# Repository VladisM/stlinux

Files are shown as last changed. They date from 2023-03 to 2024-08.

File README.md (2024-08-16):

# STlinux

Simple board with STM32F446 and SDRAM that is capable of running MMU less linux
build. Purpose of this project is to learn new stuffs. It may seems like good
thing to have Linux in such small form factor but it isn't. MMU is somehow
important in security and using this approach to build device that will be
connected to the network is a bad idea.

This project using submodules. After clone use following to init them.

```bash
$ git submodule update --init --recursive
```

## System specification

* Hardware:
    * 32MB SDRAM
    * 8MB QSPI Flash
    * UART console, sd card slot, EEPROM
    * two LEDs and two buttons
* Software
    * Linux kernel 6.3
    * Busybox 1.36.1

## Manufacturing board

Gerber files required for manufacturing are stored in `board/ger` subdirectory.
To manufacture board you shall just find yourself a suitable manufacturer
and use latest archive.

To generate BOM you shall use KiCad and revisit folder `board/kicad`. All
project files are stored there.

After soldering board you should apply ftdi configuration into
integrated UART bridge. Correct configuration is provided
by the file `board/ftdi_configuration.xml`. For that you are going
to need Windows PC and FT_PROG tool (available on their website).

To test if board was correctly manufactured and most importantly
assembled. You can use firmware available in `board_test` folder.

Compile and load firmware, connect using serial port at speed of 115200
and follow instructions.

**Warning:** at this moment SDIO and SD Card slot test are
not implemented!

## Compile system and bootloader

Everything is compiled using clfs.sh script in root folder of this project. So,
if you want to compile whole system simply call following command. (note, adjust
number of cores for compilation using -j)

```bash
$ ./clfs.sh --build all -j 8
```

After some time, you can find all output images in `build/images/`. There are:

 * bootloader - u-boot.bin
 * linux kernel - zImage
 * device tree - stm32f446-stlinux.dtb
 * system image - clfs.uImage

Bootloader shall be loaded to the board using STLink, and shall be written
to the internal Flash memory of MCU.

```bash
st-flash write build/images/u-boot.bin 0x08000000
```

Other components are by default loaded from QSPI Flash, there are two ways how
to get them there.

 * Using SD card
 * Using serial port (legacy)

### Loading QSPI Flash using serial port

This method was used for first revision of board with nonworking SD card slot.
If you have second revision of board, use SD card, it is much more faster.

Once you are in u-boot console, you can use xmodem protocol to send all files
and then write them to the QSPI Flash. For writing there is mtd command. Follow
next code snippet.

```bash
> loadx
# send kernel file (zImage) using your console emulator
> mtd erase kernel
> mtd write kernel ${loadaddr}
> loadx
# send rootfs file (clfs.uImage) using your console emulator
> mtd erase rootfs
> mtd write rootfs ${loadaddr}
> loadx
# send dtb file (stm32f446-stlinux.dtb) using your console emulator
> mtd erase rootfs
> mtd write rootfs ${loadaddr}
```

Then you can simply reset the board or type `run bootcmd` and you should be
welcomed by kernel boot log.

### Loading QSPI Flash using SD card

Compared to using serial port, this one is much much faster because data are
transferred over SD card, not xmodem at 115200 bauds.

Create one partition on your SD card, format it as FAT32, and copy there
image files from build directory. Then insert your card to the board and run
following commands.

```bash
> fatload mmc 0:1 ${loadaddr} zImage
> mtd erase kernel
> mtd write kernel ${loadaddr}
> fatload mmc 0:1 ${loadaddr} clfs.uImage
> mtd erase rootfs
> mtd write rootfs ${loadaddr}
> fatload mmc 0:1 ${loadaddr} stm32f446-stlinux.dtb
> mtd erase dtb
> mtd write dtb ${loadaddr}
```

After reset, your board will boot from QSPI Flash or you can simply type
`run bootcmd`.

### Loading directly from SD card

If you are feeling lazy, just copypaste this to bootloader console. And it will boot.

```bash
fatload mmc 0:1 ${kernel_addr_l} zImage ; fatload mmc 0:1 ${rootfs_addr_l} clfs.uImage ; fatload mmc 0:1 ${dtb_addr_l} stm32f446-stlinux.dtb ; run set_args ; bootz ${kernel_addr_l} ${rootfs_addr_l} ${dtb_addr_l}
```

It will load everything from SD card into RAM and boot kernel that way.

## License

This project is using a lot of software components that are licensed under
various licenses. Always make sure to check what component are you working
with to prevent any misunderstanding.

Board manufacturing files, firmware for testing, and build script is licensed
using the Do What The Fuck You Want To Public License, Version 2,
as published by Sam Hocevar. See COPYING file for more details.

Note: CLFS is abbreviation from Cross Linux From Scratch, in general describing process
of cross compiling [Linux From Scratch](https://www.linuxfromscratch.org/). Please
also see [CLFS project](https://trac.clfs.org/). My work is influenced by these
projects and I learned from their materials a lot.

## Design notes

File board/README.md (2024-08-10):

# Board project files

In this directory all files required for manufacturing board are gathered.
Archives with gerber files are stored in `CAM` directory. Project for KiCad
can be found in `KiCad` directory. Configuration required for FTDI chip is
next to the gerber files in `CAM` directory. There is also a CubeMX project
located in `STM32CubeMX` folder.

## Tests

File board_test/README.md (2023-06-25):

# Board testing utility

Firmware for testing board. It can detect problems
on your assembled board. For more information please
visit [doc/readme/board_test.md](../doc/readme/board_test.md).

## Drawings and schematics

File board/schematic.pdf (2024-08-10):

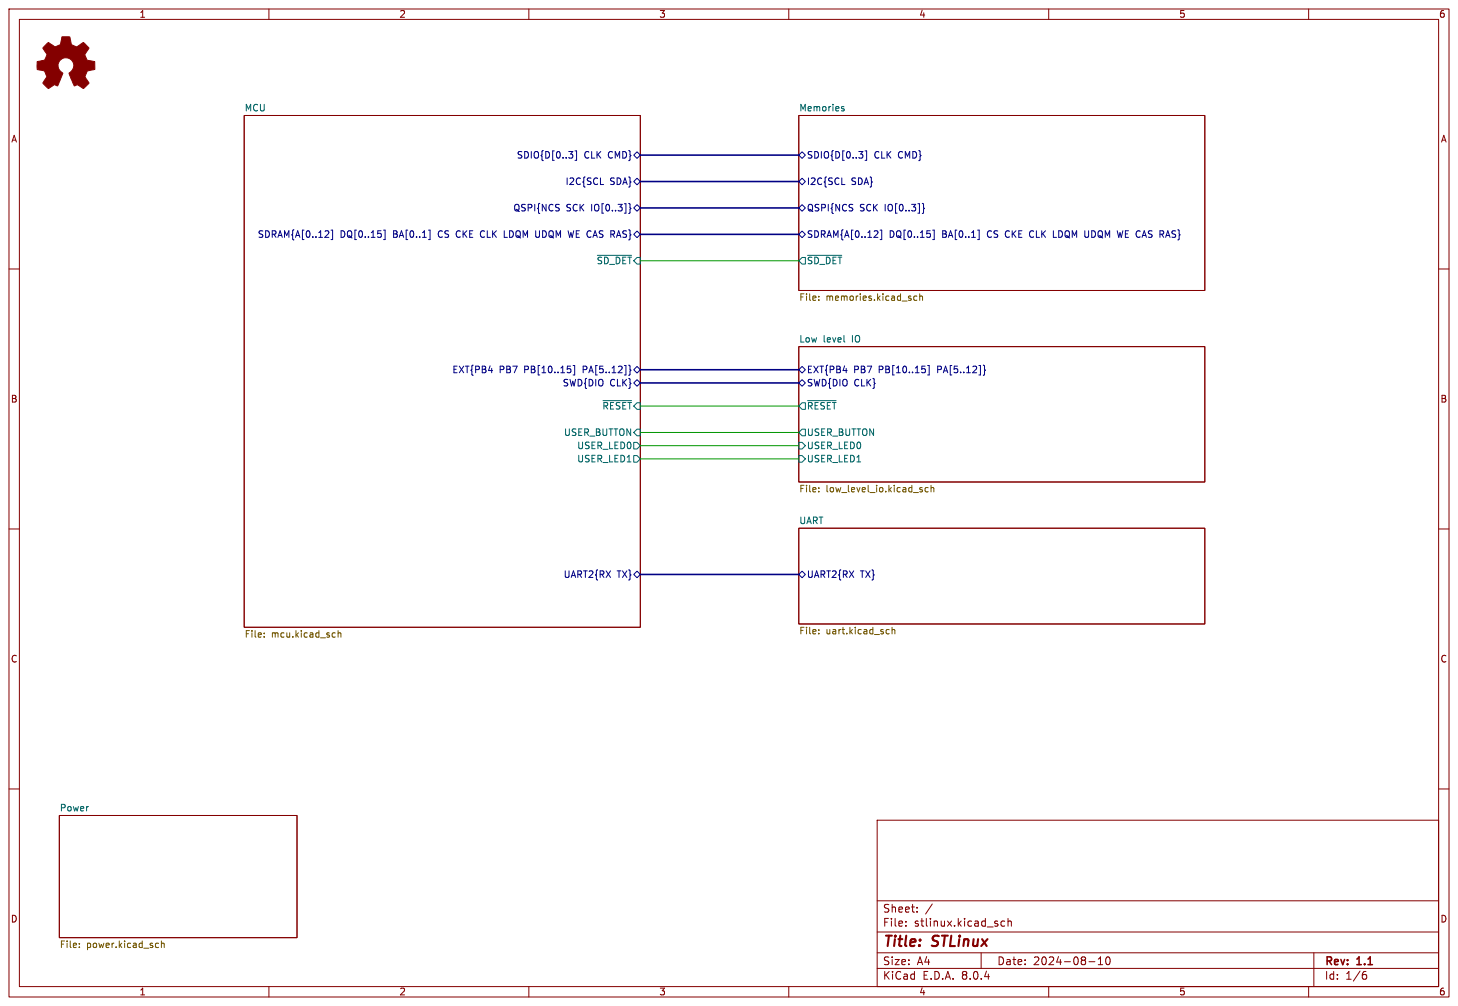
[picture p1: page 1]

File: stlinux.kicad_sch Sheet: / UART2{RX TX} UART

QSPI{NCS SCK IO[0..3]}

File: mcu.kicad_sch Power File: power.kicad_sch

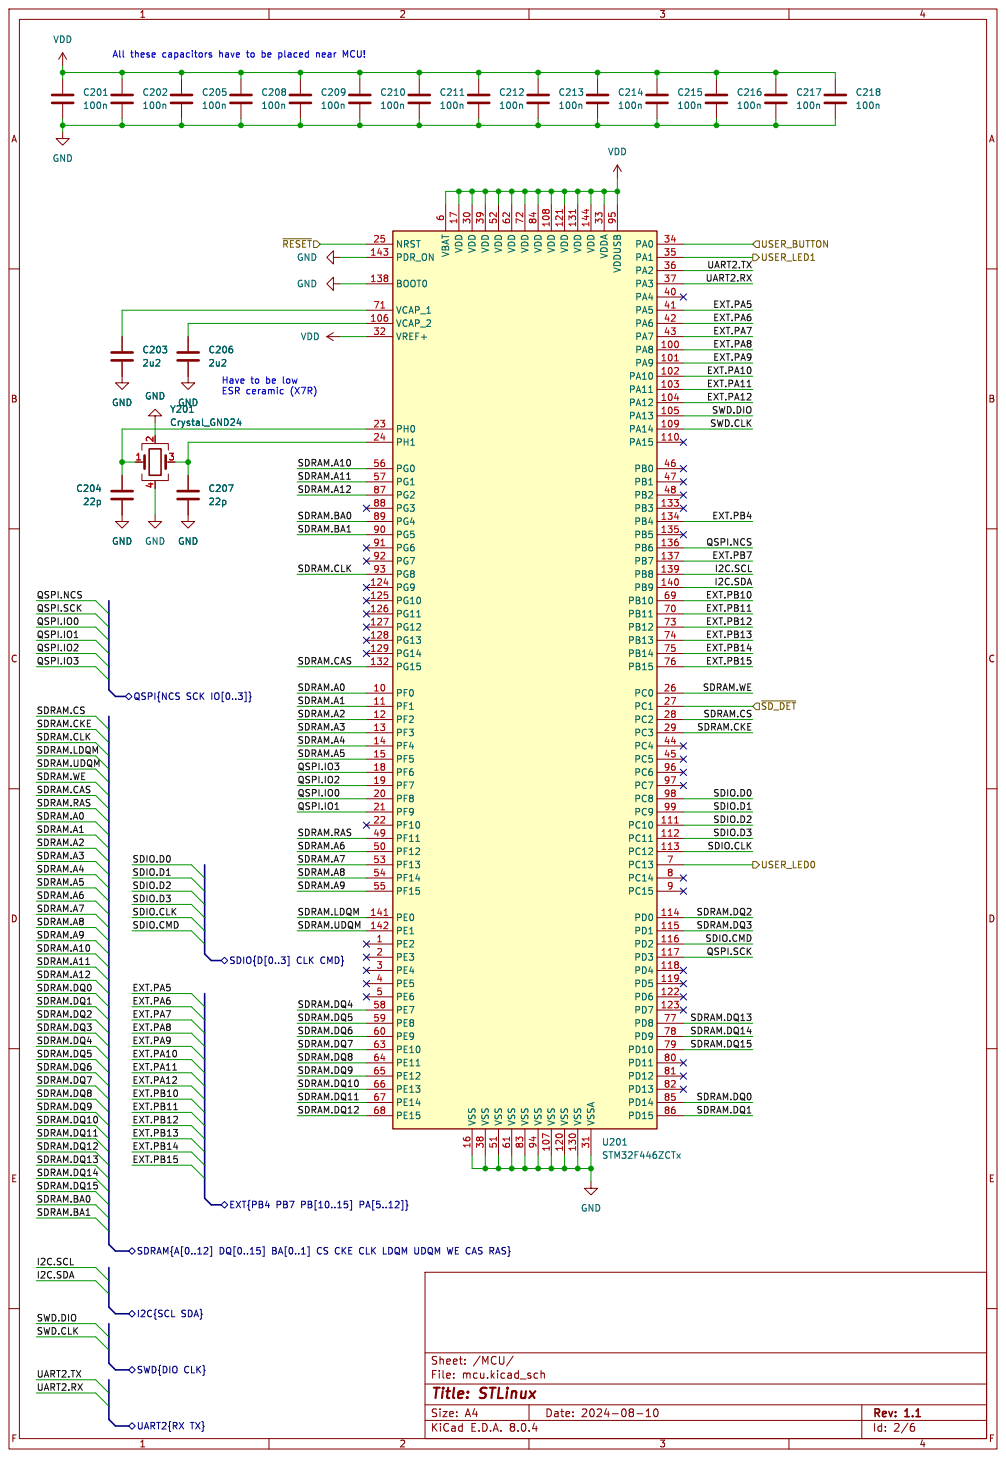
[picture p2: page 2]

EXT.PA8 EXT.PA9 EXT.PA6 EXT.PA11 EXT.PA10 EXT.PA5 UART2.TX UART2.RX QSPI.NCS

EXT.PB4 EXT.PB11 EXT.PB12 EXT.PB13 EXT.PB10

QSPI.SCK
SDRAM.CS QSPI.IO3 SDRAM.A0 SDRAM.RAS

EXT.PB15 EXT.PB14
SDRAM.CS QSPI.SCK
SDRAM.CKE

QSPI{NCS SCK IO[0..3]}

SDRAM.A2 SDRAM.A4 SDRAM.CLK
SDRAM.A3 SDRAM.CKE

SDRAM.LDQM
SDRAM.A1 SDRAM.UDQM
SDRAM.WE
SDRAM.CAS
EXT.PA6 EXT.PA5 SWD.CLK UART2.RX

SDIO.D3 SDRAM.DQ15 SDRAM.DQ13 SDRAM.DQ14 SDIO.D1 SDRAM.UDQM

File: mcu.kicad_sch Sheet: /MCU/
Id: 2/6 Title: STLinux

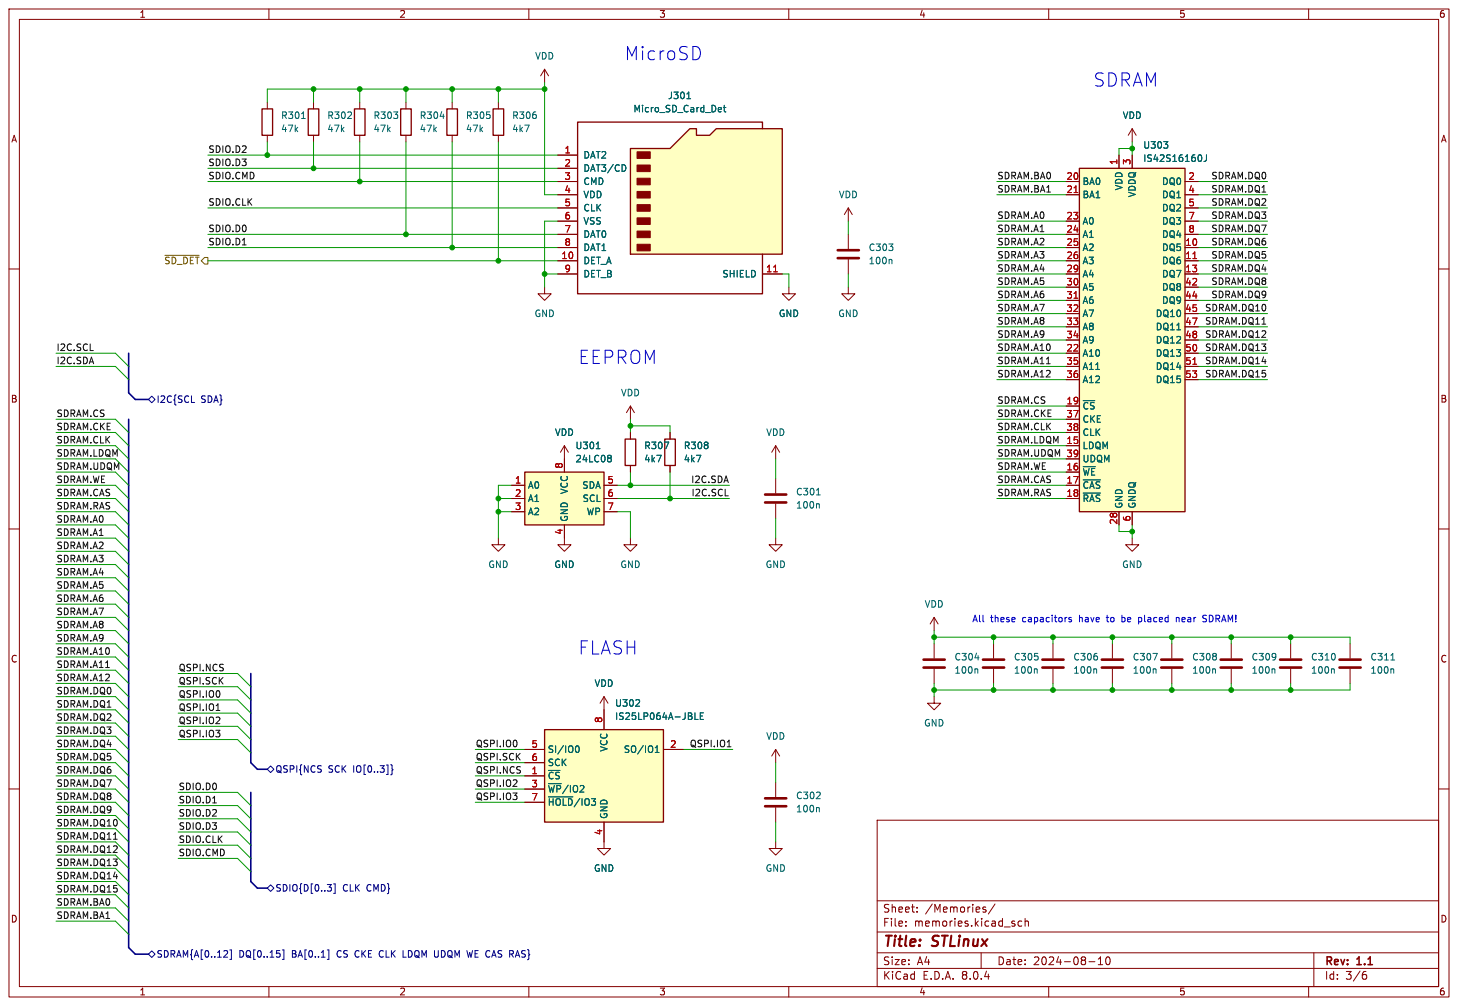
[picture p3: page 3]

J301 Micro_SD_Card_Det VDD
SDIO.D0 SDRAM.DQ12 SDRAM.DQ14 SDRAM.DQ13
SDIO.D1 QSPI.IO0 QSPI.NCS QSPI.SCK QSPI.IO3 SDIO.CMD
~{SD_DET}

SDRAM
SDRAM.A2 SDRAM.UDQM
SDRAM.A7 SDRAM.A8 SDRAM.A9 SDRAM.A10 SDRAM.A5 SDRAM.A11 SDRAM.A12 SDRAM.CS

3 A5 30 A6 31 A7 32 A8 33 A9 34 A11 35 A12 36 CKE 37 CLK 38 UDQM 39 DQ1 4 DQ8 42 DQ9 44 DQ10 45 DQ11 47 DQ12 48 DQ2 5 DQ13 50 DQ14 51 DQ15 53 GNDQ

SDRAM.DQ12 SDRAM.DQ14 SDRAM.DQ15 SDRAM.DQ4 SDRAM.DQ10 SDRAM.CKE

4 SDA 5 SCL 6 WP 7 VCC

4 SI/IO0 5 SCK 6 ~{HOLD}/IO3 7 VCC

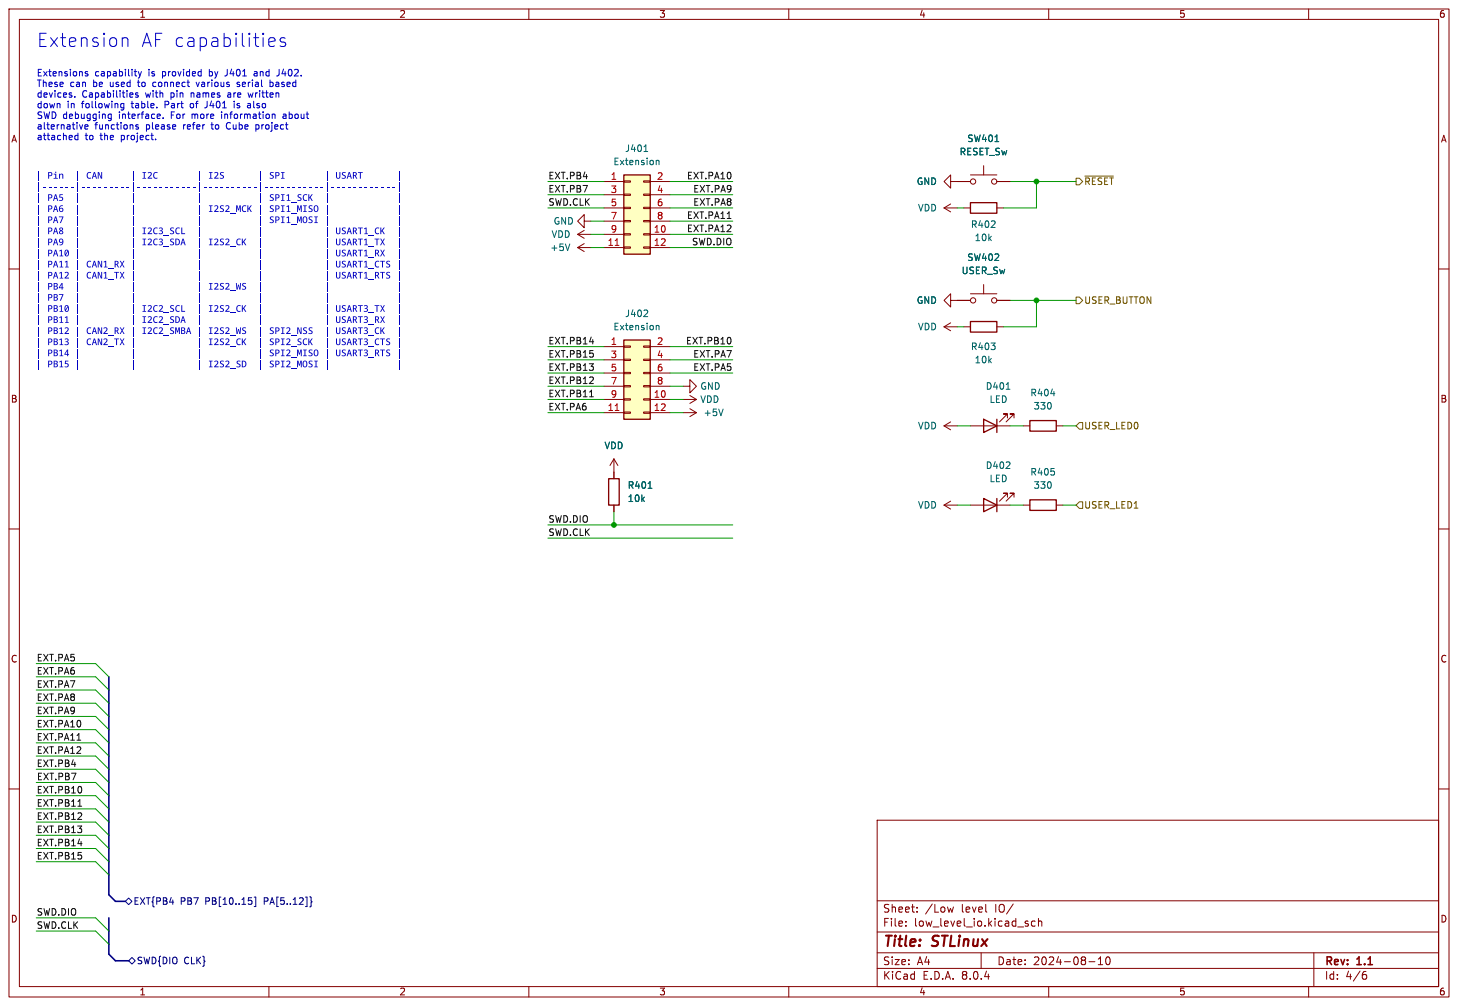
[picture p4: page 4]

EXT.PA11 EXT.PA6 SWD.DIO

EXT.PB11 EXT.PB15 EXT.PB12 EXT.PA11 EXT.PA9

EXT.PA5 SWD.CLK
EXT.PB12 EXT.PA8 EXT.PA6 EXT.PA7 EXT.PB11 EXT.PA12 EXT.PB4 EXT.PB7 EXT.PB10 EXT.PB15 EXT.PB13 EXT.PB14

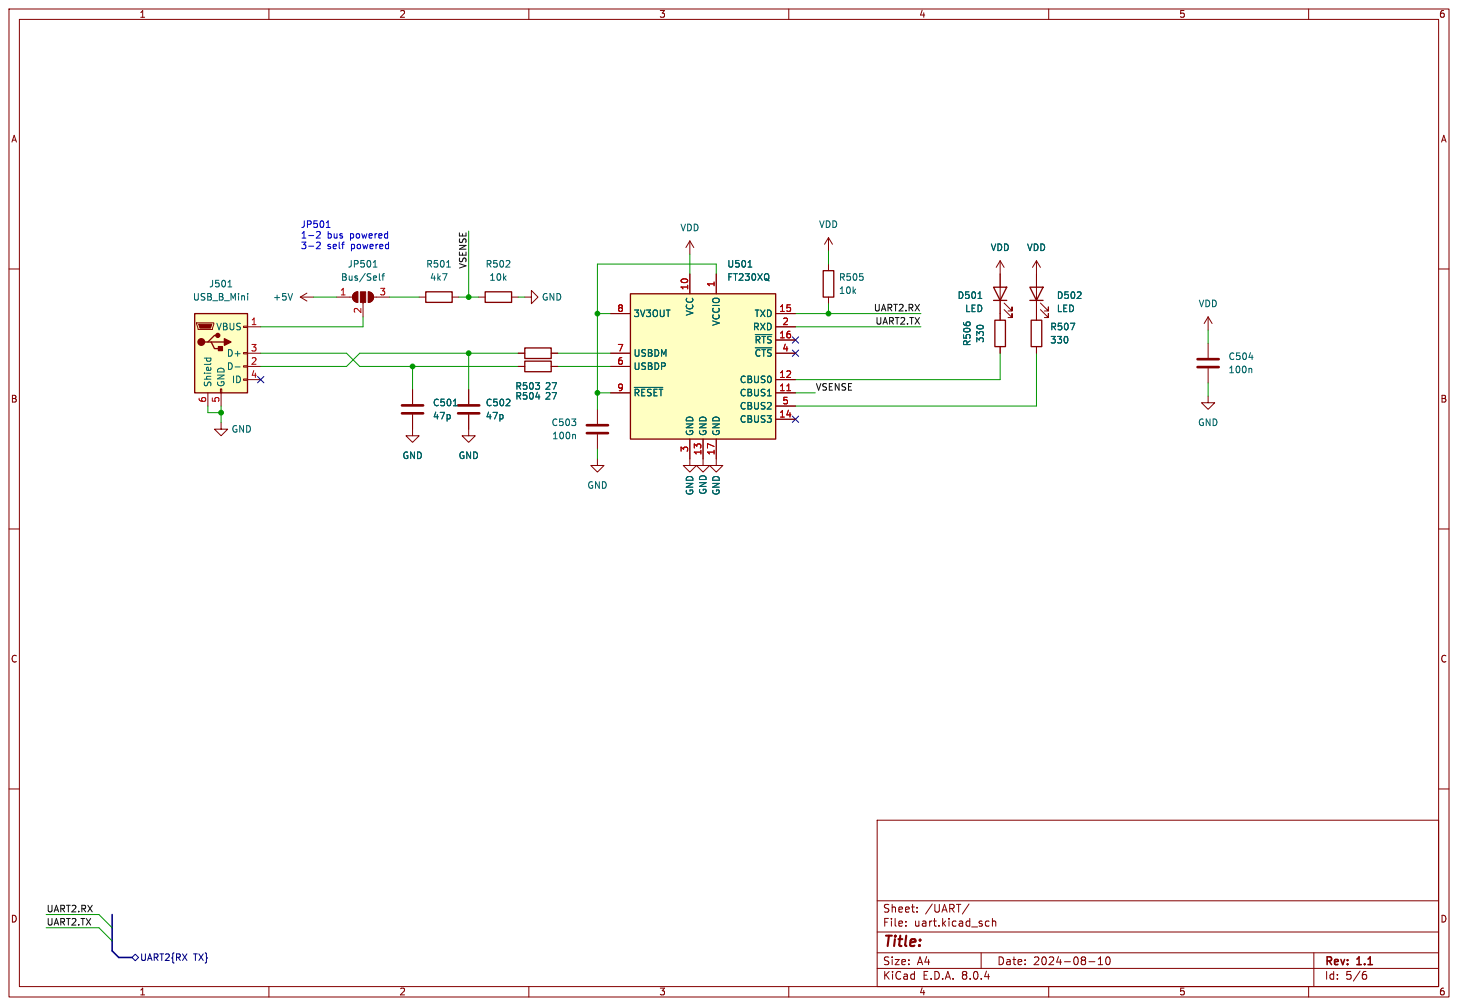
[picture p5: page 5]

1 VCC 10 CBUS1 11 CBUS0 12 GND 13 CBUS3 14 TXD 15 ~{RTS}16 GND 17 RXD 2 GND

Id: 5/6 Title: File: uart.kicad_sch Sheet: /UART/

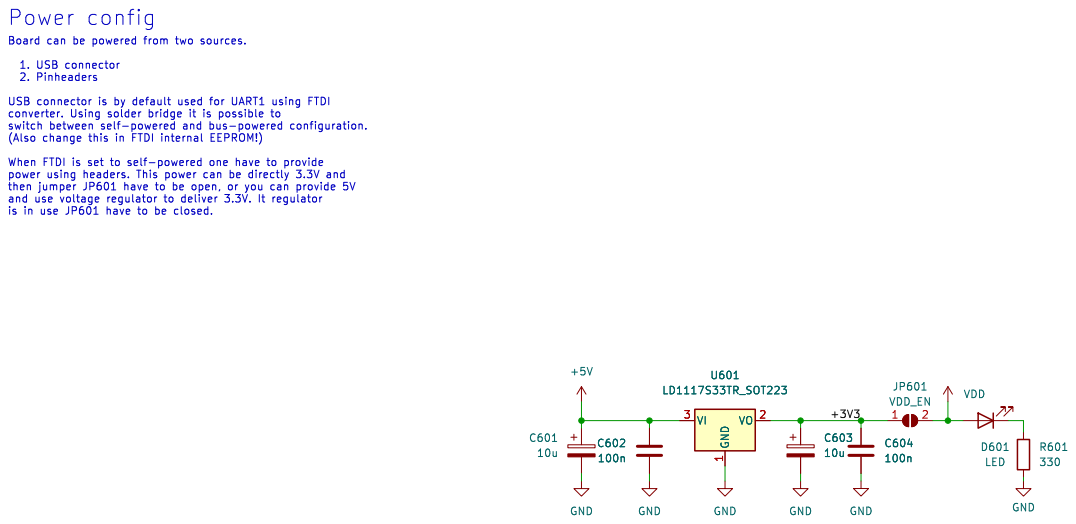
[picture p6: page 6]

then jumper JP601 have to be open, or you can provide 5V

Id: 6/6 Title: File: power.kicad_sch Sheet: /Power/

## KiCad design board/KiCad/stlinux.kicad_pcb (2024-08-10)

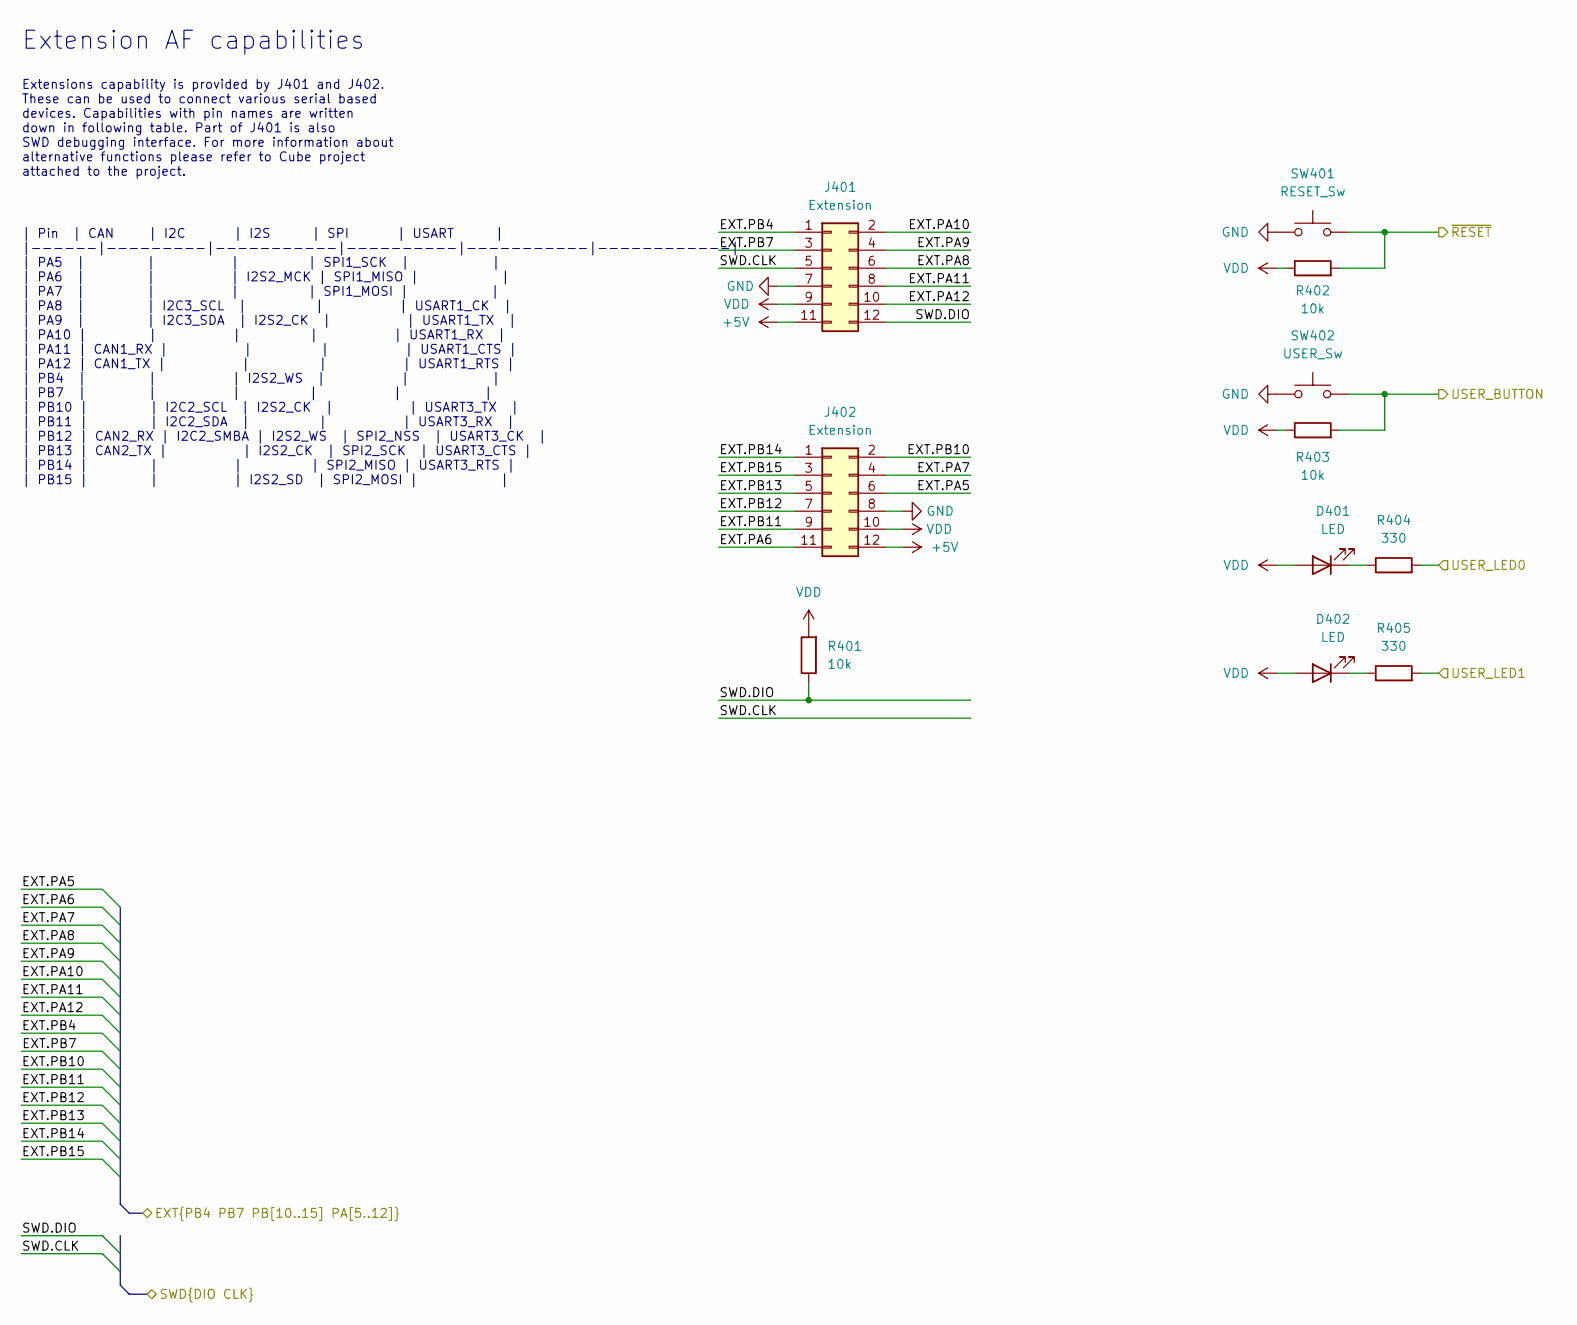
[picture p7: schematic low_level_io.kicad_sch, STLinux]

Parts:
D401, D402: LED; LED_1206_3216Metric_Pad1.42x1.75mm_HandSolder
J401, J402: Extension; PinSocket_2x06_P2.54mm_Vertical_SMD
R401, R402, R403: 10k; R_0603_1608Metric_Pad0.98x0.95mm_HandSolder
R404, R405: 330; R_0603_1608Metric_Pad0.98x0.95mm_HandSolder
SW401: RESET_Sw; SW_Push_1P1T_NO_6x6mm_H9.5mm
SW402: USER_Sw; SW_Push_1P1T_NO_6x6mm_H9.5mm

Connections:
+5V: J401.11, J402.12; also elsewhere on the board
/Low level IO/EXT.PA5: J402.6; also elsewhere on the board
/Low level IO/EXT.PA6: J402.11; also elsewhere on the board
/Low level IO/EXT.PA7: J402.4; also elsewhere on the board
/Low level IO/EXT.PA8: J401.6; also elsewhere on the board
/Low level IO/EXT.PA9: J401.4; also elsewhere on the board
/Low level IO/EXT.PA10: J401.2; also elsewhere on the board
/Low level IO/EXT.PA11: J401.8; also elsewhere on the board
/Low level IO/EXT.PA12: J401.10; also elsewhere on the board
/Low level IO/EXT.PB4: J401.1; also elsewhere on the board
/Low level IO/EXT.PB7: J401.3; also elsewhere on the board
/Low level IO/EXT.PB10: J402.2; also elsewhere on the board
/Low level IO/EXT.PB11: J402.9; also elsewhere on the board
/Low level IO/EXT.PB12: J402.7; also elsewhere on the board
/Low level IO/EXT.PB13: J402.5; also elsewhere on the board
/Low level IO/EXT.PB14: J402.1; also elsewhere on the board
/Low level IO/EXT.PB15: J402.3; also elsewhere on the board
/Low level IO/SWD.CLK: J401.5; also elsewhere on the board
/Low level IO/SWD.DIO: J401.12, R401.1; also elsewhere on the board
/Low level IO/USER_BUTTON: R403.2, SW402.2; also elsewhere on the board
/Low level IO/USER_LED0: R404.2; also elsewhere on the board
/Low level IO/USER_LED1: R405.2; also elsewhere on the board
/Low level IO/~RESET: R402.2, SW401.2; also elsewhere on the board
GND: J401.7, J402.8, SW401.1, SW402.1; also elsewhere on the board
unnamed: D401.1 (K), R404.1
unnamed: D402.1 (K), R405.1
VDD: D401.2 (A), D402.2 (A), J401.9, J402.10, R401.2, R402.1, R403.1; also elsewhere on the board

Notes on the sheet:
| Pin | CAN | I2C | I2S | SPI | USART | |------|---------|-----------|----------|-----------|------------| | PA5 | | | | SPI1_SCK | | | PA6 | | | I2S2_MCK | SPI1_MISO | | | PA7 | | | | SPI1_MOSI | | | PA8 | | I2C3_SCL | | | USART1_CK | | PA9 | | I2C3_SDA | I2S2_CK | | USART1_TX | | PA10 | | | | | U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
Extensions capability is provided by J401 and J402. These can be used to connect various serial based devices. Capabilities with pin names are written down in following table. Part of J401 is also SWD debugging interface. For more information about alternative functions please refer to Cube project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
Extension AF capabilities

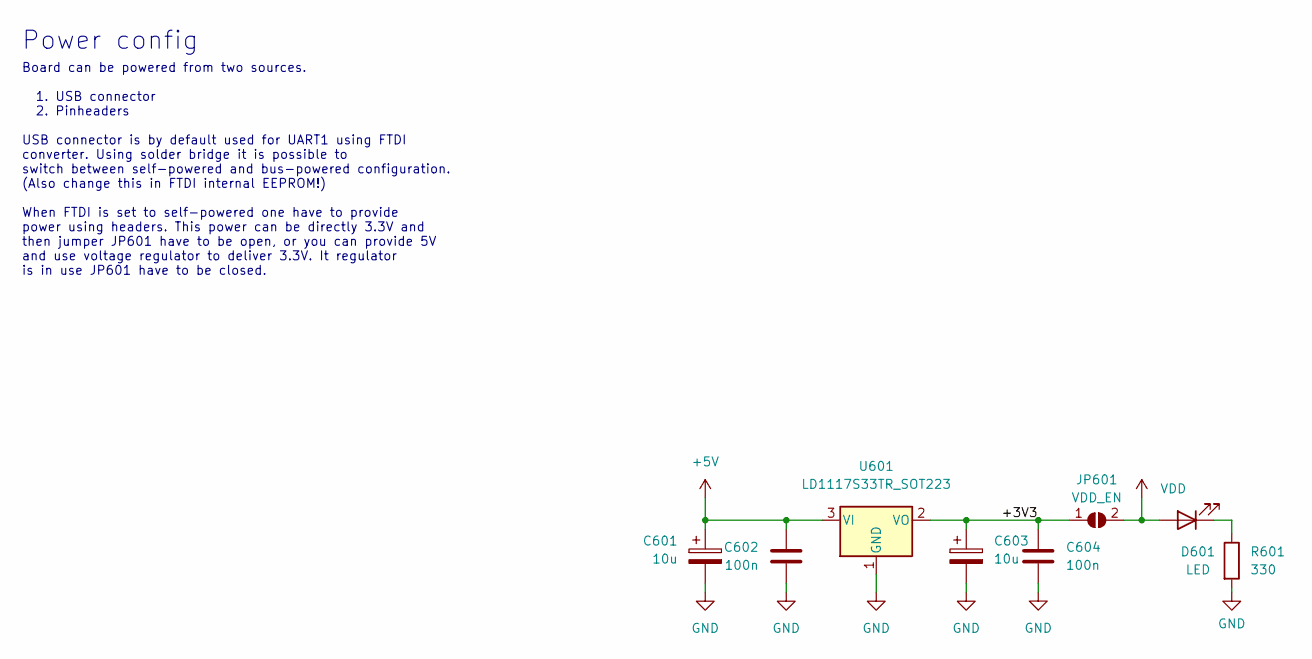
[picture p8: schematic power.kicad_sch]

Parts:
C601, C603: 10u; CP_EIA-3216-18_Kemet-A_Pad1.58x1.35mm_HandSolder
C602, C604: 100n; C_0603_1608Metric_Pad1.08x0.95mm_HandSolder
D601: LED; LED_1206_3216Metric_Pad1.42x1.75mm_HandSolder
JP601: VDD_EN; SolderJumper-2_P1.3mm_Open_RoundedPad1.0x1.5mm
R601: 330; R_0603_1608Metric_Pad0.98x0.95mm_HandSolder
U601: LD1117S33TR_SOT223; SOT-223-3_TabPin2

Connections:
+5V: C601.1, C602.1, U601.3 (VI); also elsewhere on the board
/Power/+3V3: C603.1, C604.1, JP601.1 (A), U601.2 (VO)
GND: C601.2, C602.2, C603.2, C604.2, R601.2, U601.1 (GND); also elsewhere on the board
unnamed: D601.1 (K), R601.1
VDD: D601.2 (A), JP601.2 (B); also elsewhere on the board

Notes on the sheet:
Power config
Board can be powered from two sources. 1. USB connector 2. Pinheaders USB connector is by default used for UART1 using FTDI converter. Using solder bridge it is possible to switch between self-powered and bus-powered configuration. (Also change this in FTDI internal EEPROM!) When FTDI is set to sel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

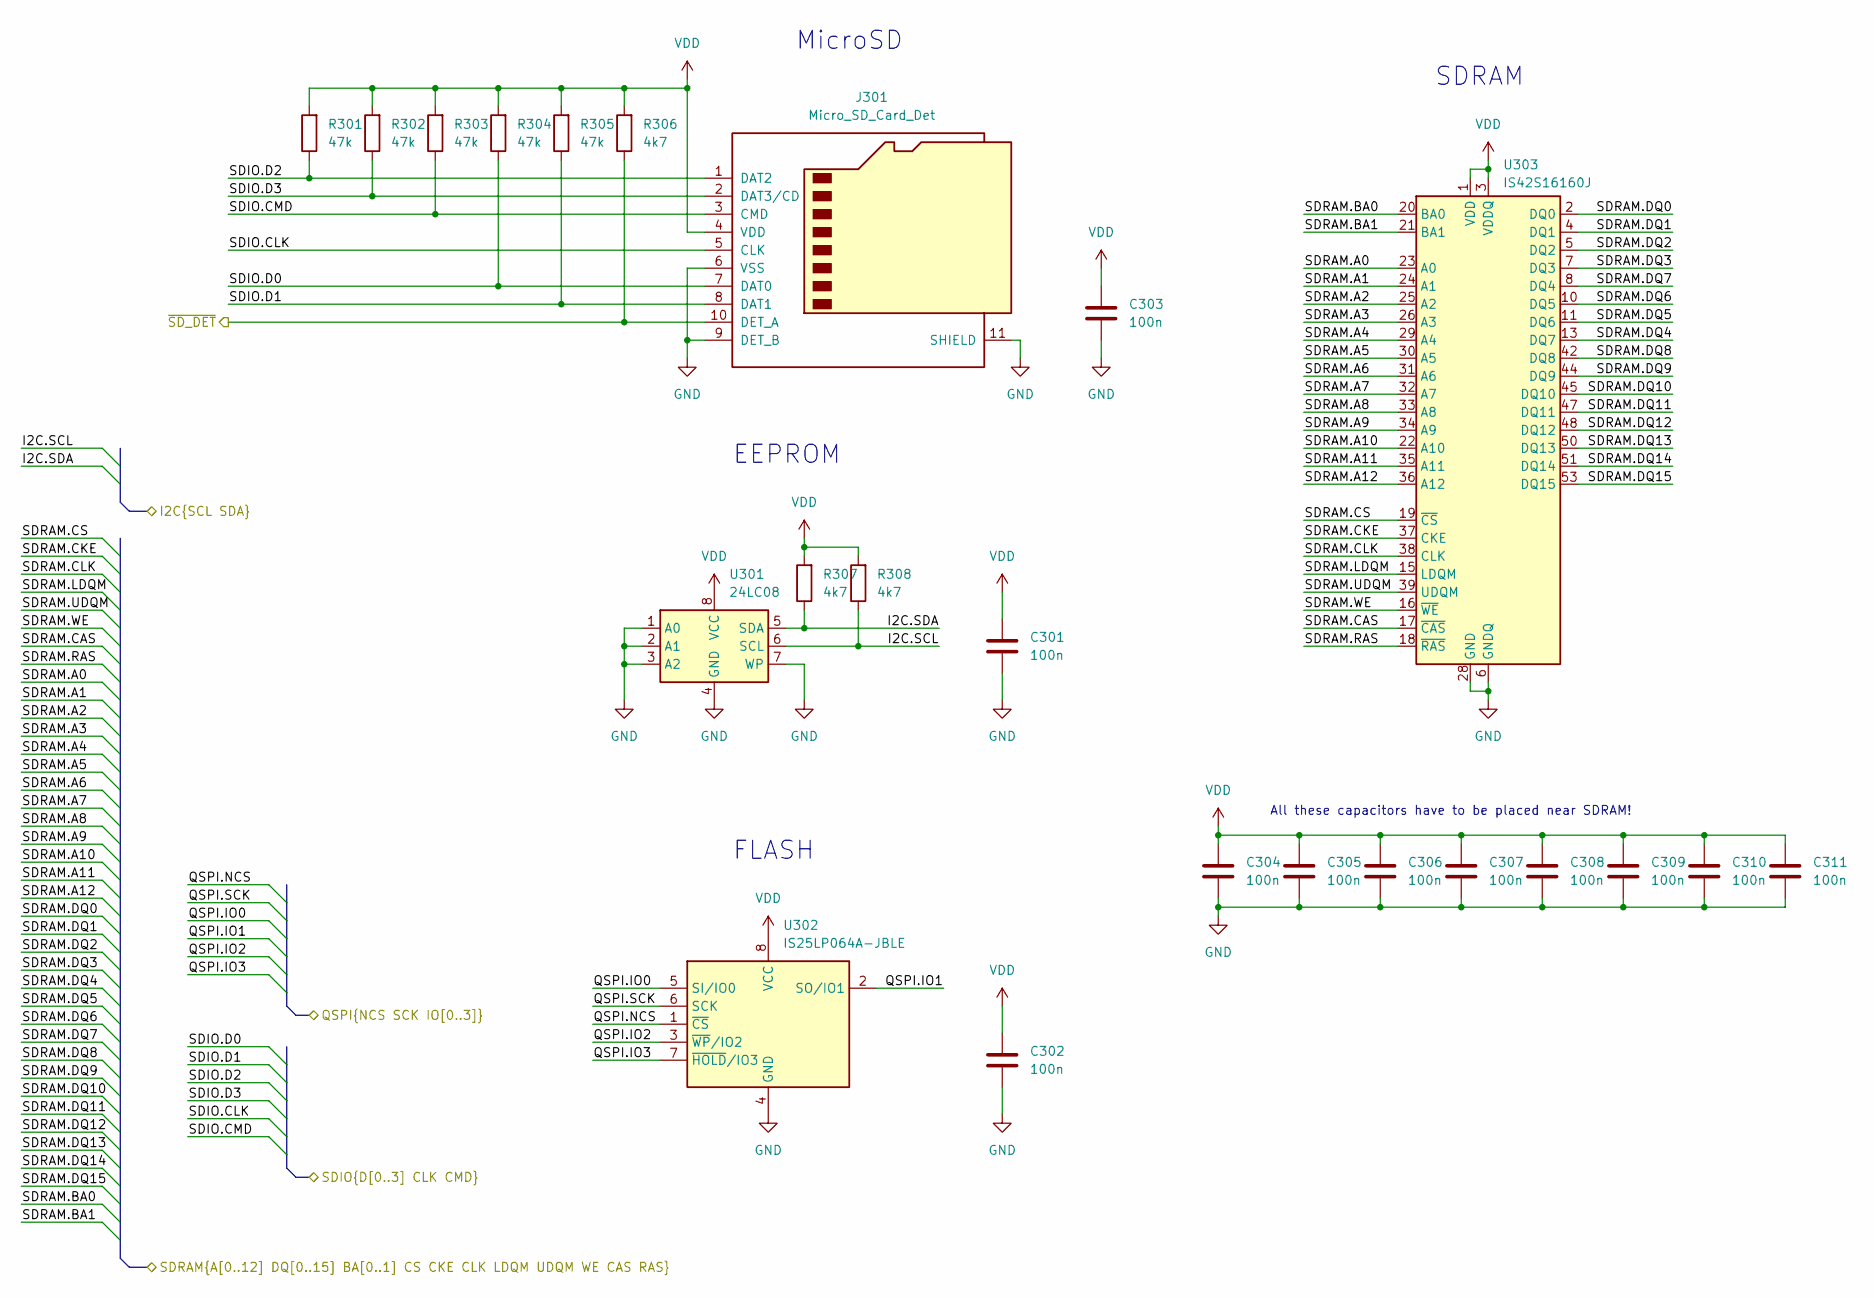
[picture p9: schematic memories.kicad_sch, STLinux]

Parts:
C301, C302, C303, C304, C305, C306, C307, C308, C309, C310, C311: 100n; C_0603_1608Metric_Pad1.08x0.95mm_HandSolder
J301: Micro_SD_Card_Det; microSD_HC_Molex_104031-0811
R301, R302, R303, R304, R305: 47k; R_0603_1608Metric_Pad0.98x0.95mm_HandSolder
R306, R307, R308: 4k7; R_0603_1608Metric_Pad0.98x0.95mm_HandSolder
U301: 24LC08; SOP-8_3.9x4.9mm_P1.27mm
U302: IS25LP064A-JBLE; SOIC-8_5.23x5.23mm_P1.27mm
U303: IS42S16160J; TSOP-II-54_22.2x10.16mm_P0.8mm

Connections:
/MCU/I2C.SCL: R308.1, U301.6 (SCL); also elsewhere on the board
/MCU/I2C.SDA: R307.1, U301.5 (SDA); also elsewhere on the board
/MCU/QSPI.IO0: U302.5 (SI/IO0); also elsewhere on the board
/MCU/QSPI.IO1: U302.2 (SO/IO1); also elsewhere on the board
/MCU/QSPI.IO2: U302.3 (~WP/IO2); also elsewhere on the board
/MCU/QSPI.IO3: U302.7 (~HOLD/IO3); also elsewhere on the board
/MCU/QSPI.NCS: U302.1 (~CS); also elsewhere on the board
/MCU/QSPI.SCK: U302.6 (SCK); also elsewhere on the board
/MCU/SDIO.CLK: J301.5 (CLK); also elsewhere on the board
/MCU/SDIO.CMD: J301.3 (CMD), R303.1; also elsewhere on the board
/MCU/SDIO.D0: J301.7 (DAT0), R304.1; also elsewhere on the board
/MCU/SDIO.D1: J301.8 (DAT1), R305.1; also elsewhere on the board
/MCU/SDIO.D2: J301.1 (DAT2), R301.1; also elsewhere on the board
/MCU/SDIO.D3: J301.2 (DAT3/CD), R302.1; also elsewhere on the board
/MCU/SDRAM.A0: U303.23 (A0); also elsewhere on the board
/MCU/SDRAM.A1: U303.24 (A1); also elsewhere on the board
/MCU/SDRAM.A2: U303.25 (A2); also elsewhere on the board
/MCU/SDRAM.A3: U303.26 (A3); also elsewhere on the board
/MCU/SDRAM.A4: U303.29 (A4); also elsewhere on the board
/MCU/SDRAM.A5: U303.30 (A5); also elsewhere on the board
/MCU/SDRAM.A6: U303.31 (A6); also elsewhere on the board
/MCU/SDRAM.A7: U303.32 (A7); also elsewhere on the board
/MCU/SDRAM.A8: U303.33 (A8); also elsewhere on the board
/MCU/SDRAM.A9: U303.34 (A9); also elsewhere on the board
/MCU/SDRAM.A10: U303.22 (A10); also elsewhere on the board
/MCU/SDRAM.A11: U303.35 (A11); also elsewhere on the board
/MCU/SDRAM.A12: U303.36 (A12); also elsewhere on the board
/MCU/SDRAM.BA0: U303.20 (BA0); also elsewhere on the board
/MCU/SDRAM.BA1: U303.21 (BA1); also elsewhere on the board
/MCU/SDRAM.CAS: U303.17 (~CAS); also elsewhere on the board
/MCU/SDRAM.CKE: U303.37 (CKE); also elsewhere on the board
/MCU/SDRAM.CLK: U303.38 (CLK); also elsewhere on the board
/MCU/SDRAM.CS: U303.19 (~CS); also elsewhere on the board
/MCU/SDRAM.DQ0: U303.2 (DQ0); also elsewhere on the board
/MCU/SDRAM.DQ1: U303.4 (DQ1); also elsewhere on the board
/MCU/SDRAM.DQ2: U303.5 (DQ2); also elsewhere on the board
/MCU/SDRAM.DQ3: U303.7 (DQ3); also elsewhere on the board
/MCU/SDRAM.DQ4: U303.13 (DQ7); also elsewhere on the board
/MCU/SDRAM.DQ5: U303.11 (DQ6); also elsewhere on the board
/MCU/SDRAM.DQ6: U303.10 (DQ5); also elsewhere on the board
/MCU/SDRAM.DQ7: U303.8 (DQ4); also elsewhere on the board
/MCU/SDRAM.DQ8: U303.42 (DQ8); also elsewhere on the board
/MCU/SDRAM.DQ9: U303.44 (DQ9); also elsewhere on the board
/MCU/SDRAM.DQ10: U303.45 (DQ10); also elsewhere on the board
/MCU/SDRAM.DQ11: U303.47 (DQ11); also elsewhere on the board
/MCU/SDRAM.DQ12: U303.48 (DQ12); also elsewhere on the board
/MCU/SDRAM.DQ13: U303.50 (DQ13); also elsewhere on the board
/MCU/SDRAM.DQ14: U303.51 (DQ14); also elsewhere on the board
/MCU/SDRAM.DQ15: U303.53 (DQ15); also elsewhere on the board
/MCU/SDRAM.LDQM: U303.15 (LDQM); also elsewhere on the board
/MCU/SDRAM.RAS: U303.18 (~RAS); also elsewhere on the board
/MCU/SDRAM.UDQM: U303.39 (UDQM); also elsewhere on the board
/MCU/SDRAM.WE: U303.16 (~WE); also elsewhere on the board
/MCU/~SD_DET: J301.10 (DET_A), R306.1; also elsewhere on the board
GND: C301.2, C302.2, C303.2, C304.2, C305.2, C306.2, C307.2, C308.2, C309.2, C310.2, C311.2, J301.6 (VSS), J301.9 (DET_B), J301.11 (SHIELD), U301.1 (A0), U301.2 (A1), U301.3 (A2), U301.4 (GND), U301.7 (WP), U302.4 (GND), U303.6 (GNDQ), U303.12 (GNDQ), U303.28 (GND), U303.41 (GND), U303.46 (GNDQ), U303.52 (GNDQ), U303.54 (GND); also elsewhere on the board
VDD: C301.1, C302.1, C303.1, C304.1, C305.1, C306.1, C307.1, C308.1, C309.1, C310.1, C311.1, J301.4 (VDD), R301.2, R302.2, R303.2, R304.2, R305.2, R306.2, R307.2, R308.2, U301.8 (VCC), U302.8 (VCC), U303.1 (VDD), U303.3 (VDDQ), U303.9 (VDDQ), U303.14 (VDD), U303.27 (VDD), U303.43 (VDDQ), U303.49 (VDDQ); also elsewhere on the board

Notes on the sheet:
EEPROM
All these capacitors have to be placed near SDRAM!
FLASH
MicroSD
SDRAM

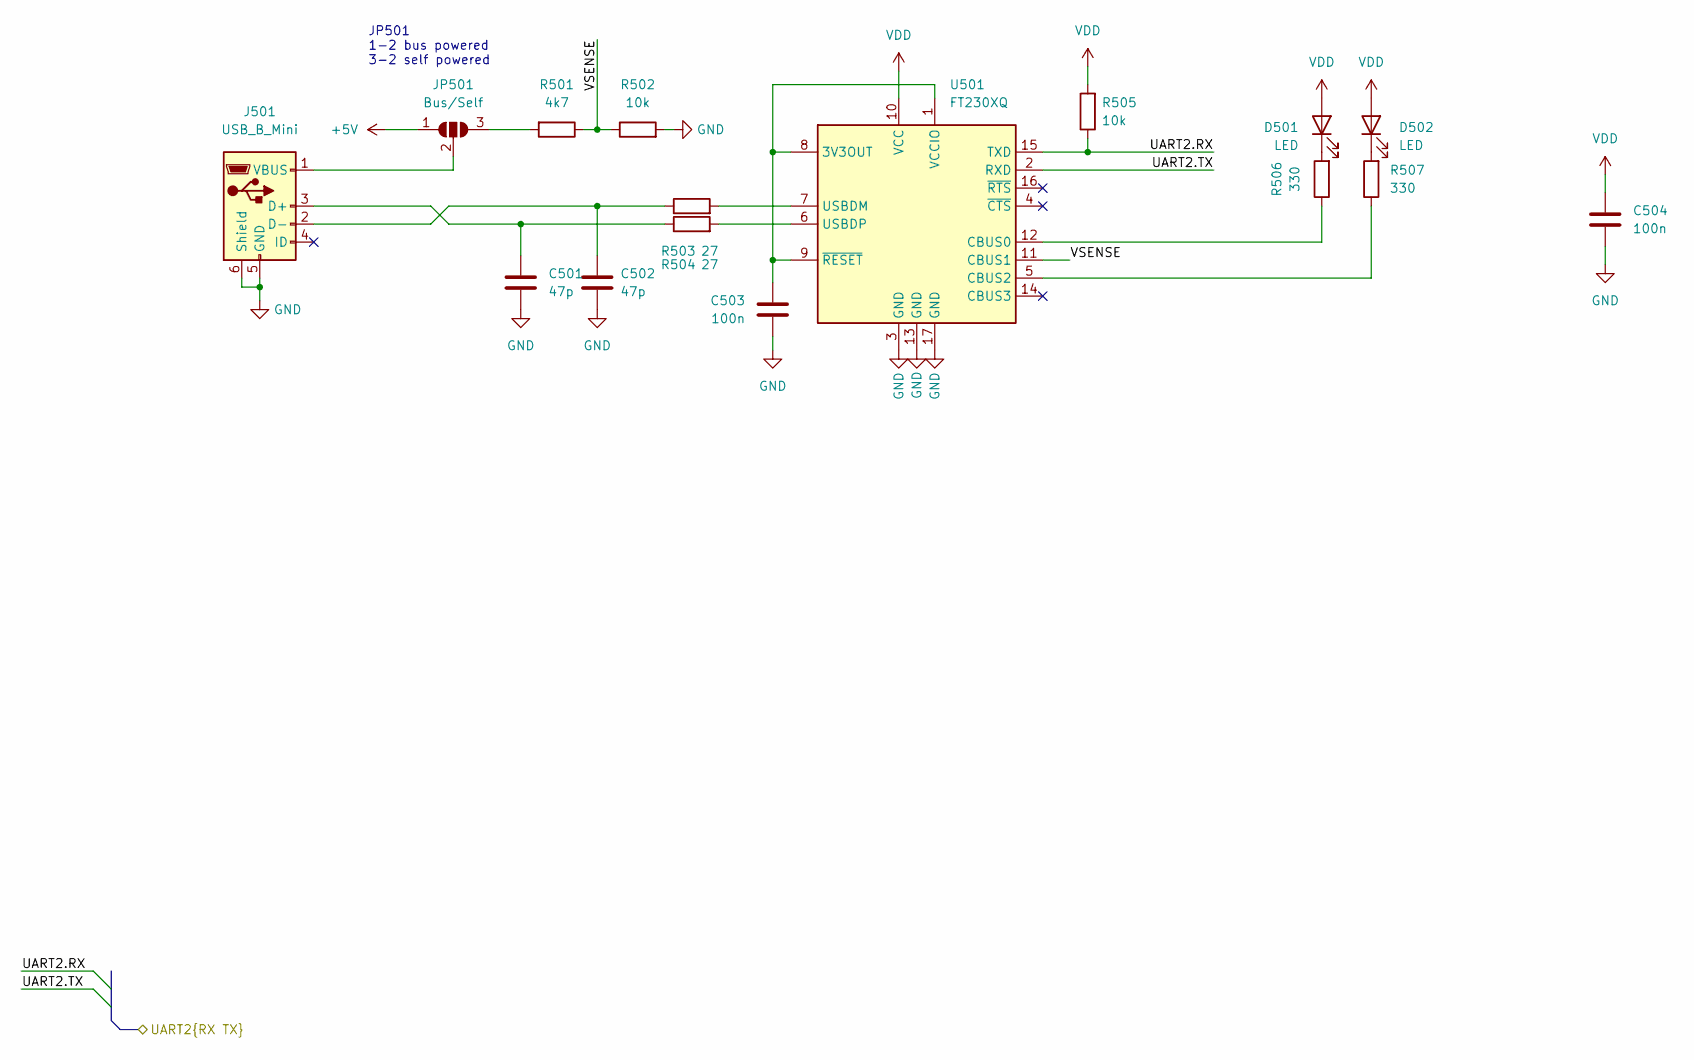
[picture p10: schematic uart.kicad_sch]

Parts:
C501, C502: 47p; C_0603_1608Metric_Pad1.08x0.95mm_HandSolder
C503, C504: 100n; C_0603_1608Metric_Pad1.08x0.95mm_HandSolder
D501, D502: LED; LED_1206_3216Metric_Pad1.42x1.75mm_HandSolder
J501: USB_B_Mini; USB_Mini-B_Wuerth_65100516121_Horizontal
JP501: Bus/Self; SolderJumper-3_P1.3mm_Open_RoundedPad1.0x1.5mm_NumberLabels
R501: 4k7; R_0603_1608Metric_Pad0.98x0.95mm_HandSolder
R502, R505: 10k; R_0603_1608Metric_Pad0.98x0.95mm_HandSolder
R503, R504: 27; R_0603_1608Metric_Pad0.98x0.95mm_HandSolder
R506, R507: 330; R_0603_1608Metric_Pad0.98x0.95mm_HandSolder
U501: FT230XQ; QFN-16-1EP_4x4mm_P0.65mm_EP2.1x2.1mm

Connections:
+5V: JP501.1 (A); also elsewhere on the board
/MCU/UART2.RX: R505.1, U501.15 (TXD); also elsewhere on the board
/MCU/UART2.TX: U501.2 (RXD); also elsewhere on the board
/UART/VSENSE: R501.1, R502.1, U501.11 (CBUS1)
GND: C501.2, C502.2, C503.2, C504.2, J501.5 (GND), J501.6 (Shield), R502.2, U501.3 (GND), U501.13 (GND), U501.17 (GND); also elsewhere on the board
unnamed: D501.1 (K), R506.2
unnamed: D502.1 (K), R507.2
unnamed: C501.1, J501.3 (D+), R504.1
unnamed: C502.1, J501.2 (D-), R503.1
unnamed: J501.1 (VBUS), JP501.2 (C)
unnamed: JP501.3 (B), R501.2
unnamed: C503.1, U501.1 (VCCIO), U501.8 (3V3OUT), U501.9 (~RESET)
unnamed: R506.1, U501.12 (CBUS0)
unnamed: R507.1, U501.5 (CBUS2)
unnamed: R503.2, U501.7 (USBDM)
unnamed: R504.2, U501.6 (USBDP)
VDD: C504.1, D501.2 (A), D502.2 (A), R505.2, U501.10 (VCC); also elsewhere on the board

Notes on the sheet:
JP501 1-2 bus powered 3-2 self powered

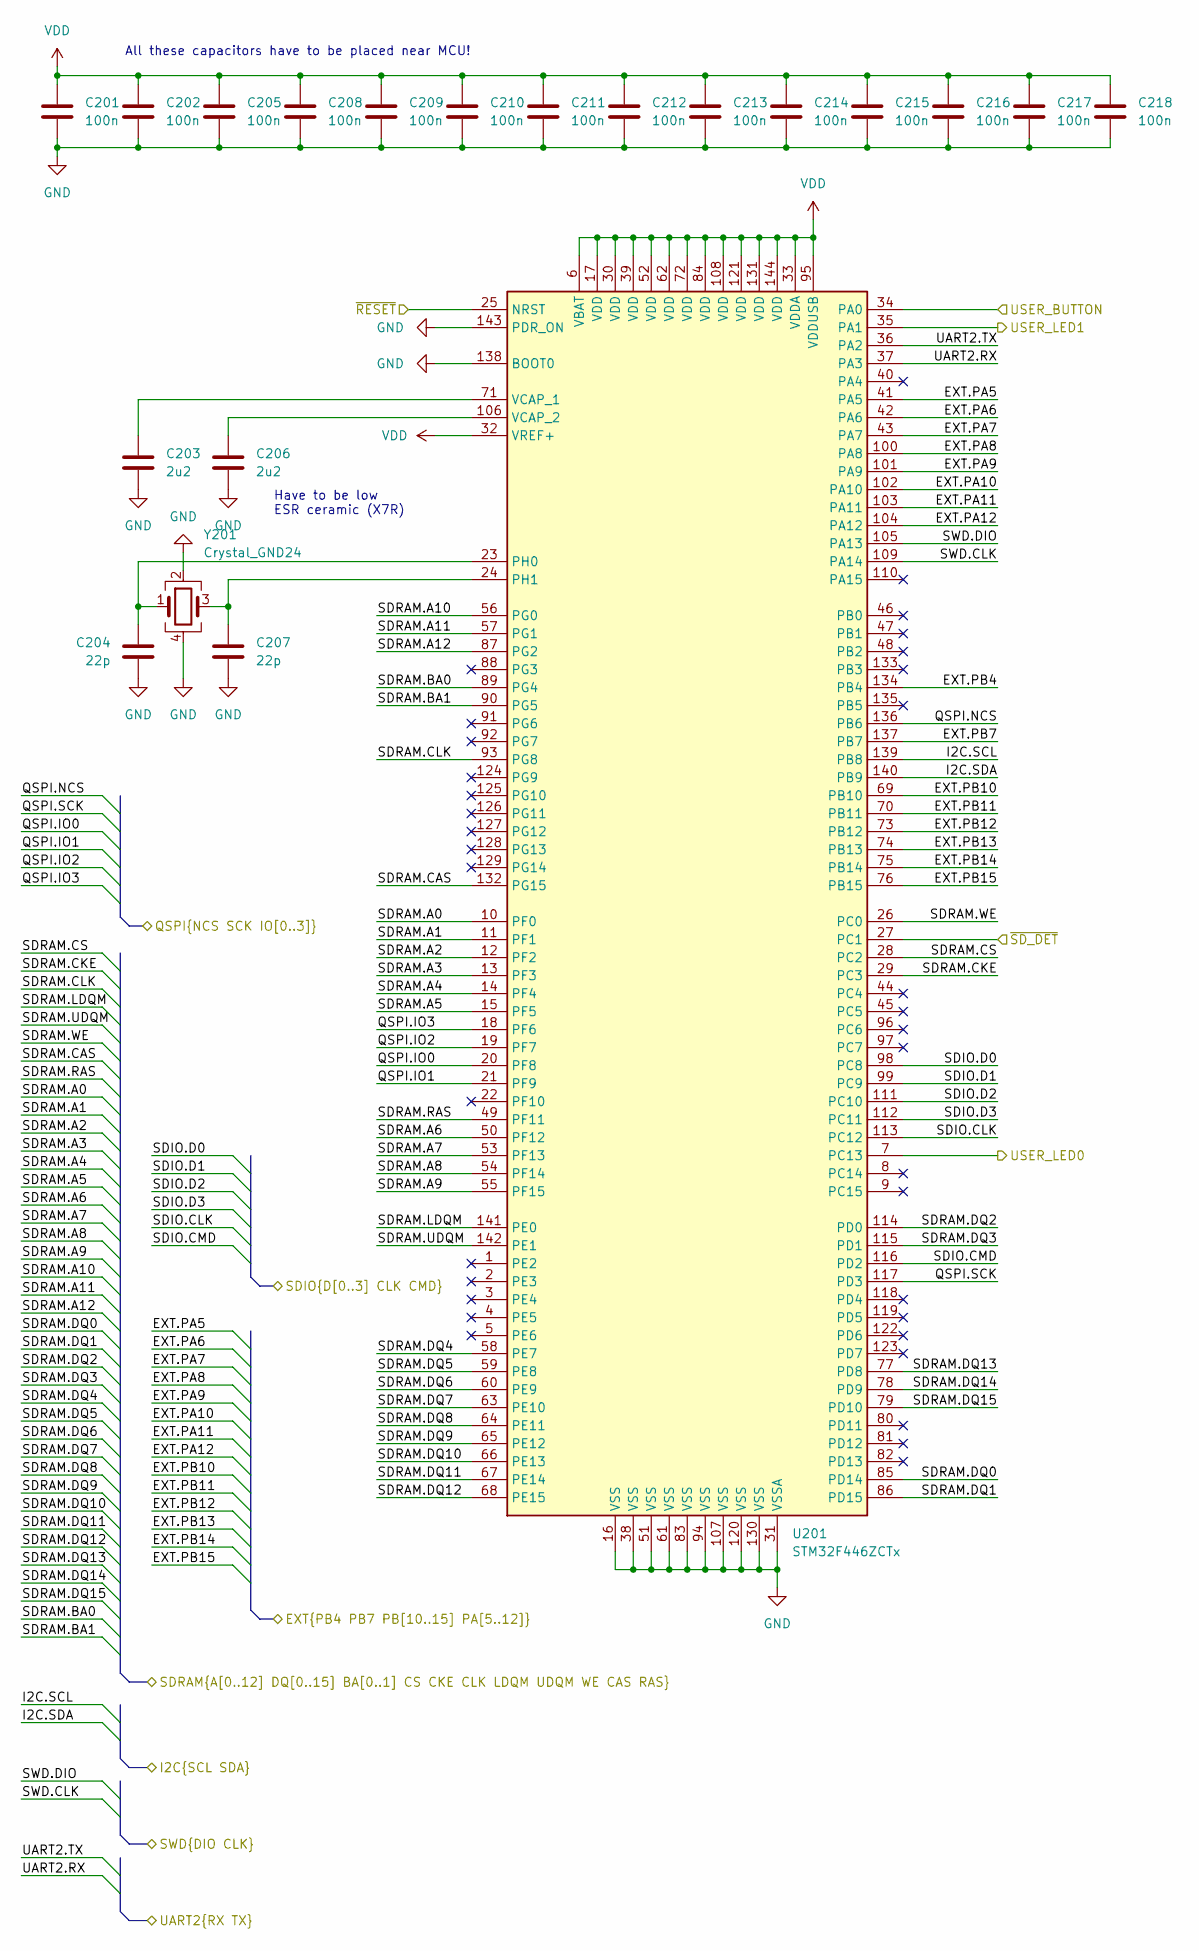
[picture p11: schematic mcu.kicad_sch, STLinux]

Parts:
C201, C202, C205, C208, C209, C210, C211, C212, C213, C214, C215, C216, C217, C218: 100n; C_0603_1608Metric_Pad1.08x0.95mm_HandSolder
C203, C206: 2u2; C_0603_1608Metric_Pad1.08x0.95mm_HandSolder
C204, C207: 22p; C_0603_1608Metric_Pad1.08x0.95mm_HandSolder
U201: STM32F446ZCTx; LQFP-144_20x20mm_P0.5mm
Y201: Crystal_GND24; Crystal_SMD_3225-4Pin_3.2x2.5mm_HandSoldering

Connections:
/Low level IO/EXT.PA5: U201.41 (PA5); also elsewhere on the board
/Low level IO/EXT.PA6: U201.42 (PA6); also elsewhere on the board
/Low level IO/EXT.PA7: U201.43 (PA7); also elsewhere on the board
/Low level IO/EXT.PA8: U201.100 (PA8); also elsewhere on the board
/Low level IO/EXT.PA9: U201.101 (PA9); also elsewhere on the board
/Low level IO/EXT.PA10: U201.102 (PA10); also elsewhere on the board
/Low level IO/EXT.PA11: U201.103 (PA11); also elsewhere on the board
/Low level IO/EXT.PA12: U201.104 (PA12); also elsewhere on the board
/Low level IO/EXT.PB4: U201.134 (PB4); also elsewhere on the board
/Low level IO/EXT.PB7: U201.137 (PB7); also elsewhere on the board
/Low level IO/EXT.PB10: U201.69 (PB10); also elsewhere on the board
/Low level IO/EXT.PB11: U201.70 (PB11); also elsewhere on the board
/Low level IO/EXT.PB12: U201.73 (PB12); also elsewhere on the board
/Low level IO/EXT.PB13: U201.74 (PB13); also elsewhere on the board
/Low level IO/EXT.PB14: U201.75 (PB14); also elsewhere on the board
/Low level IO/EXT.PB15: U201.76 (PB15); also elsewhere on the board
/Low level IO/SWD.CLK: U201.109 (PA14); also elsewhere on the board
/Low level IO/SWD.DIO: U201.105 (PA13); also elsewhere on the board
/Low level IO/USER_BUTTON: U201.34 (PA0); also elsewhere on the board
/Low level IO/USER_LED0: U201.7 (PC13); also elsewhere on the board
/Low level IO/USER_LED1: U201.35 (PA1); also elsewhere on the board
/Low level IO/~RESET: U201.25 (NRST); also elsewhere on the board
/MCU/I2C.SCL: U201.139 (PB8); also elsewhere on the board
/MCU/I2C.SDA: U201.140 (PB9); also elsewhere on the board
/MCU/QSPI.IO0: U201.20 (PF8); also elsewhere on the board
/MCU/QSPI.IO1: U201.21 (PF9); also elsewhere on the board
/MCU/QSPI.IO2: U201.19 (PF7); also elsewhere on the board
/MCU/QSPI.IO3: U201.18 (PF6); also elsewhere on the board
/MCU/QSPI.NCS: U201.136 (PB6); also elsewhere on the board
/MCU/QSPI.SCK: U201.117 (PD3); also elsewhere on the board
/MCU/SDIO.CLK: U201.113 (PC12); also elsewhere on the board
/MCU/SDIO.CMD: U201.116 (PD2); also elsewhere on the board
/MCU/SDIO.D0: U201.98 (PC8); also elsewhere on the board
/MCU/SDIO.D1: U201.99 (PC9); also elsewhere on the board
/MCU/SDIO.D2: U201.111 (PC10); also elsewhere on the board
/MCU/SDIO.D3: U201.112 (PC11); also elsewhere on the board
/MCU/SDRAM.A0: U201.10 (PF0); also elsewhere on the board
/MCU/SDRAM.A1: U201.11 (PF1); also elsewhere on the board
/MCU/SDRAM.A2: U201.12 (PF2); also elsewhere on the board
/MCU/SDRAM.A3: U201.13 (PF3); also elsewhere on the board
/MCU/SDRAM.A4: U201.14 (PF4); also elsewhere on the board
/MCU/SDRAM.A5: U201.15 (PF5); also elsewhere on the board
/MCU/SDRAM.A6: U201.50 (PF12); also elsewhere on the board
/MCU/SDRAM.A7: U201.53 (PF13); also elsewhere on the board
/MCU/SDRAM.A8: U201.54 (PF14); also elsewhere on the board
/MCU/SDRAM.A9: U201.55 (PF15); also elsewhere on the board
/MCU/SDRAM.A10: U201.56 (PG0); also elsewhere on the board
/MCU/SDRAM.A11: U201.57 (PG1); also elsewhere on the board
/MCU/SDRAM.A12: U201.87 (PG2); also elsewhere on the board
/MCU/SDRAM.BA0: U201.89 (PG4); also elsewhere on the board
/MCU/SDRAM.BA1: U201.90 (PG5); also elsewhere on the board
/MCU/SDRAM.CAS: U201.132 (PG15); also elsewhere on the board
/MCU/SDRAM.CKE: U201.29 (PC3); also elsewhere on the board
/MCU/SDRAM.CLK: U201.93 (PG8); also elsewhere on the board
/MCU/SDRAM.CS: U201.28 (PC2); also elsewhere on the board
/MCU/SDRAM.DQ0: U201.85 (PD14); also elsewhere on the board
/MCU/SDRAM.DQ1: U201.86 (PD15); also elsewhere on the board
/MCU/SDRAM.DQ2: U201.114 (PD0); also elsewhere on the board
/MCU/SDRAM.DQ3: U201.115 (PD1); also elsewhere on the board
/MCU/SDRAM.DQ4: U201.58 (PE7); also elsewhere on the board
/MCU/SDRAM.DQ5: U201.59 (PE8); also elsewhere on the board
/MCU/SDRAM.DQ6: U201.60 (PE9); also elsewhere on the board
/MCU/SDRAM.DQ7: U201.63 (PE10); also elsewhere on the board
/MCU/SDRAM.DQ8: U201.64 (PE11); also elsewhere on the board
/MCU/SDRAM.DQ9: U201.65 (PE12); also elsewhere on the board
/MCU/SDRAM.DQ10: U201.66 (PE13); also elsewhere on the board
/MCU/SDRAM.DQ11: U201.67 (PE14); also elsewhere on the board
/MCU/SDRAM.DQ12: U201.68 (PE15); also elsewhere on the board
/MCU/SDRAM.DQ13: U201.77 (PD8); also elsewhere on the board
/MCU/SDRAM.DQ14: U201.78 (PD9); also elsewhere on the board
/MCU/SDRAM.DQ15: U201.79 (PD10); also elsewhere on the board
/MCU/SDRAM.LDQM: U201.141 (PE0); also elsewhere on the board
/MCU/SDRAM.RAS: U201.49 (PF11); also elsewhere on the board
/MCU/SDRAM.UDQM: U201.142 (PE1); also elsewhere on the board
/MCU/SDRAM.WE: U201.26 (PC0); also elsewhere on the board
/MCU/UART2.RX: U201.37 (PA3); also elsewhere on the board
/MCU/UART2.TX: U201.36 (PA2); also elsewhere on the board
/MCU/~SD_DET: U201.27 (PC1); also elsewhere on the board
GND: C201.2, C202.2, C203.2, C204.2, C205.2, C206.2, C207.2, C208.2, C209.2, C210.2, C211.2, C212.2, C213.2, C214.2, C215.2, C216.2, C217.2, C218.2, U201.16 (VSS), U201.31 (VSSA), U201.38 (VSS), U201.51 (VSS), U201.61 (VSS), U201.83 (VSS), U201.94 (VSS), U201.107 (VSS), U201.120 (VSS), U201.130 (VSS), U201.138 (BOOT0), U201.143 (PDR_ON), Y201.2, Y201.4; also elsewhere on the board
unnamed: C204.1, U201.23 (PH0), Y201.1
unnamed: C207.1, U201.24 (PH1), Y201.3
unnamed: C203.1, U201.71 (VCAP_1)
unnamed: C206.1, U201.106 (VCAP_2)
VDD: C201.1, C202.1, C205.1, C208.1, C209.1, C210.1, C211.1, C212.1, C213.1, C214.1, C215.1, C216.1, C217.1, C218.1, U201.6 (VBAT), U201.17 (VDD), U201.30 (VDD), U201.32 (VREF+), U201.33 (VDDA), U201.39 (VDD), U201.52 (VDD), U201.62 (VDD), U201.72 (VDD), U201.84 (VDD), U201.95 (VDDUSB), U201.108 (VDD), U201.121 (VDD), U201.131 (VDD), U201.144 (VDD); also elsewhere on the board

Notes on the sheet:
Have to be low ESR ceramic (X7R)
All these capacitors have to be placed near MCU!

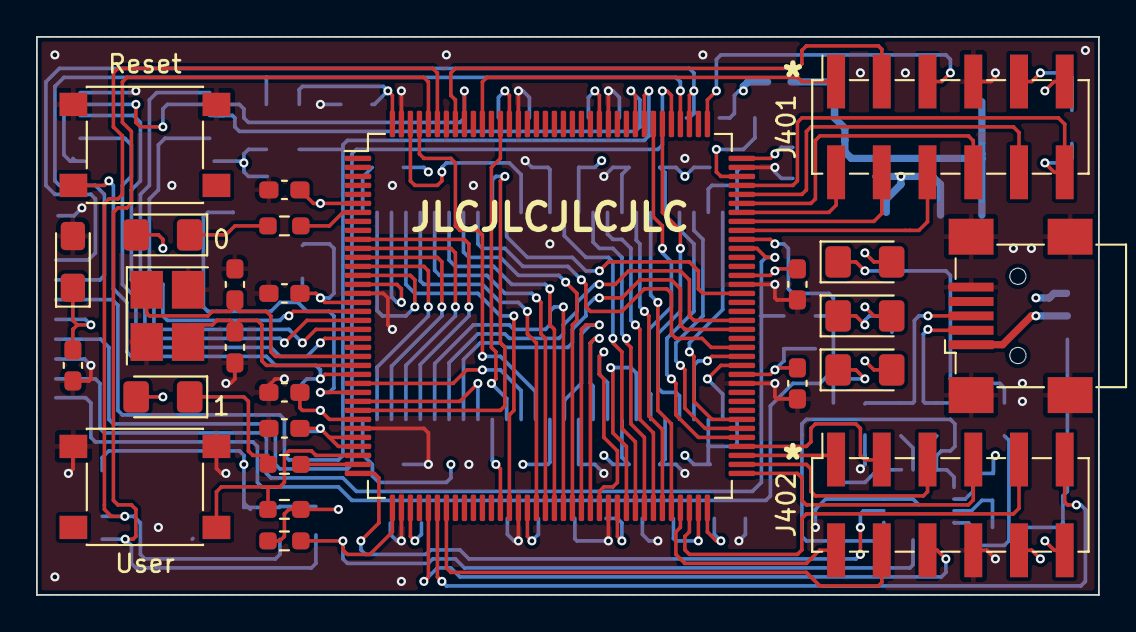
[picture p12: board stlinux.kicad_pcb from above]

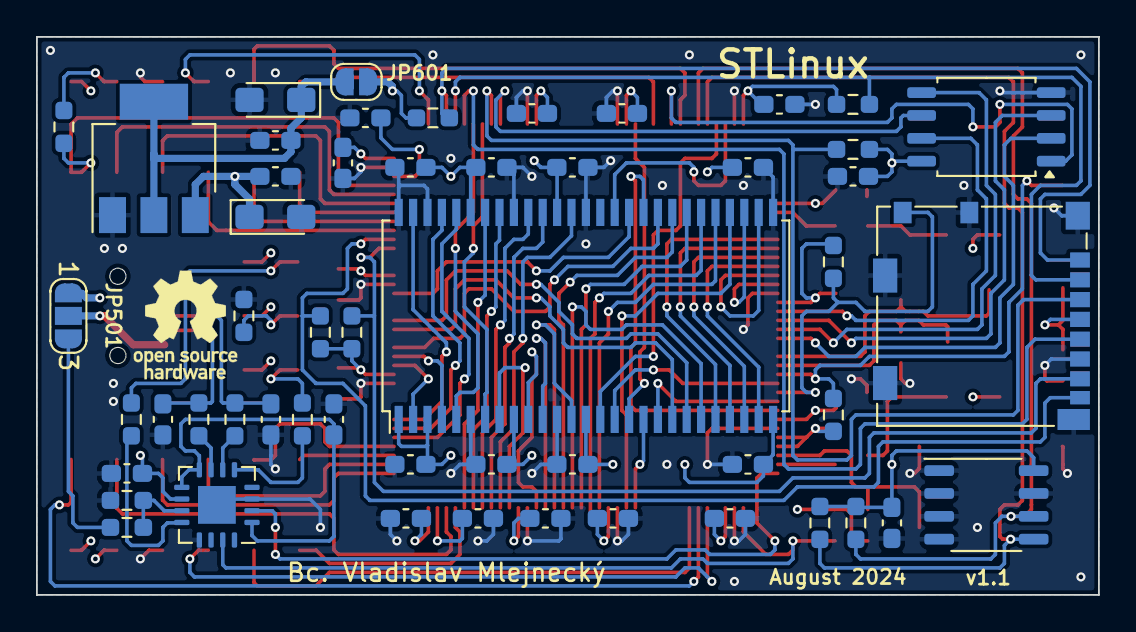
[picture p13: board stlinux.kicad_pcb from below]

Board: 4 copper layers, 59.0 x 31.0 mm, 79 parts (53 on the bottom side), 101 nets.

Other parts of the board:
C304#2: 100n; C_0603_1608Metric_Pad1.08x0.95mm_HandSolder

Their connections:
GND: C304#2.2; also elsewhere on the board
VDD: C304#2.1; also elsewhere on the board

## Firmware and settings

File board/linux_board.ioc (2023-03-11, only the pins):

Mcu.UserName=STM32F446ZCTx
PA0-WKUP.GPIO_Label=USER_BUTTON
PA0-WKUP.Signal=GPIO_Input
PA1.GPIO_Label=USER_LED1
PA1.Signal=GPIO_Output
PA13.Signal=SYS_JTMS-SWDIO
PA14.Signal=SYS_JTCK-SWCLK
PA2.Signal=USART2_TX
PA3.Signal=USART2_RX
PB6.Signal=QUADSPI_BK1_NCS
PB8.Signal=I2C1_SCL
PB9.Signal=I2C1_SDA
PC0.Signal=FMC_SDNWE
PC1.GPIO_Label=SD_DET
PC1.Signal=GPIO_Input
PC10.Signal=SDIO_D2
PC11.Signal=SDIO_D3
PC12.Signal=SDIO_CK
PC13.GPIO_Label=USER_LED0
PC13.Signal=GPIO_Output
PC2.Signal=FMC_SDNE0
PC3.Signal=FMC_SDCKE0
PC8.Signal=SDIO_D0
PC9.Signal=SDIO_D1
PD0.Signal=FMC_D2_DA2
PD1.Signal=FMC_D3_DA3
PD10.Signal=FMC_D15_DA15
PD14.Signal=FMC_D0_DA0
PD15.Signal=FMC_D1_DA1
PD2.Signal=SDIO_CMD
PD3.Signal=QUADSPI_CLK
PD8.Signal=FMC_D13_DA13
PD9.Signal=FMC_D14_DA14
PE0.Signal=FMC_NBL0
PE1.Signal=FMC_NBL1
PE10.Signal=FMC_D7_DA7
PE11.Signal=FMC_D8_DA8
PE12.Signal=FMC_D9_DA9
PE13.Signal=FMC_D10_DA10
PE14.Signal=FMC_D11_DA11
PE15.Signal=FMC_D12_DA12
PE7.Signal=FMC_D4_DA4
PE8.Signal=FMC_D5_DA5
PE9.Signal=FMC_D6_DA6
PF0.Signal=FMC_A0
PF1.Signal=FMC_A1
PF11.Signal=FMC_SDNRAS
PF12.Signal=FMC_A6
PF13.Signal=FMC_A7
PF14.Signal=FMC_A8
PF15.Signal=FMC_A9
PF2.Signal=FMC_A2
PF3.Signal=FMC_A3
PF4.Signal=FMC_A4
PF5.Signal=FMC_A5
PF6.Signal=QUADSPI_BK1_IO3
PF7.Signal=QUADSPI_BK1_IO2
PF8.Signal=QUADSPI_BK1_IO0
PF9.Signal=QUADSPI_BK1_IO1
PG0.Signal=FMC_A10
PG1.Signal=FMC_A11
PG15.Signal=FMC_SDNCAS
PG2.Signal=FMC_A12
PG4.Signal=FMC_A14_BA0
PG5.Signal=FMC_A15_BA1
PG8.Signal=FMC_SDCLK
PH0-OSC_IN.Signal=RCC_OSC_IN
PH1-OSC_OUT.Signal=RCC_OSC_OUT

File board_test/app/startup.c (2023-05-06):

#include <stdint.h>

extern int main(void);
extern void SystemInit(void);
extern void SystemCoreClockUpdate(void);

typedef void( *const intfunc )( void );

extern uint32_t _textdata;
extern uint32_t _sdata;
extern uint32_t _edata;
extern uint32_t _bss_start;
extern uint32_t _bss_end;
extern uint32_t _estack;

void crt0(void);
void reset_handler(void);
void default_handler(void);
void default_clock_init(void);

void __attribute__ ((weak, alias ("default_clock_init"))) ClockInit(void);

void __attribute__ ((weak, alias ("default_handler"))) NMI_Handler(void);
void __attribute__ ((weak, alias ("default_handler"))) HardFault_Handler(void);
void __attribute__ ((weak, alias ("default_handler"))) MemManage_Handler(void);
void __attribute__ ((weak, alias ("default_handler"))) BusFault_Handler(void);
void __attribute__ ((weak, alias ("default_handler"))) UsageFault_Handler(void);
void __attribute__ ((weak, alias ("default_handler"))) SVC_Handler(void);
void __attribute__ ((weak, alias ("default_handler"))) DebugMon_Handler(void);
void __attribute__ ((weak, alias ("default_handler"))) PendSV_Handler(void);
void __attribute__ ((weak, alias ("default_handler"))) SysTick_Handler(void);

void __attribute__ ((weak, alias ("default_handler"))) WWDG_IRQHandler(void);
void __attribute__ ((weak, alias ("default_handler"))) PVD_IRQHandler(void);
void __attribute__ ((weak, alias ("default_handler"))) TAMP_STAMP_IRQHandler(void);
void __attribute__ ((weak, alias ("default_handler"))) RTC_WKUP_IRQHandler(void);
void __attribute__ ((weak, alias ("default_handler"))) FLASH_IRQHandler(void);
void __attribute__ ((weak, alias ("default_handler"))) RCC_IRQHandler(void);
void __attribute__ ((weak, alias ("default_handler"))) EXTI0_IRQHandler(void);
void __attribute__ ((weak, alias ("default_handler"))) EXTI1_IRQHandler(void);
void __attribute__ ((weak, alias ("default_handler"))) EXTI2_IRQHandler(void);
void __attribute__ ((weak, alias ("default_handler"))) EXTI3_IRQHandler(void);
void __attribute__ ((weak, alias ("default_handler"))) EXTI4_IRQHandler(void);
void __attribute__ ((weak, alias ("default_handler"))) DMA1_Stream0_IRQHandler(void);
void __attribute__ ((weak, alias ("default_handler"))) DMA1_Stream1_IRQHandler(void);
void __attribute__ ((weak, alias ("default_handler"))) DMA1_Stream2_IRQHandler(void);
void __attribute__ ((weak, alias ("default_handler"))) DMA1_Stream3_IRQHandler(void);
void __attribute__ ((weak, alias ("default_handler"))) DMA1_Stream4_IRQHandler(void);
void __attribute__ ((weak, alias ("default_handler"))) DMA1_Stream5_IRQHandler(void);
void __attribute__ ((weak, alias ("default_handler"))) DMA1_Stream6_IRQHandler(void);
void __attribute__ ((weak, alias ("default_handler"))) ADC_IRQHandler(void);
void __attribute__ ((weak, alias ("default_handler"))) CAN1_TX_IRQHandler(void);
void __attribute__ ((weak, alias ("default_handler"))) CAN1_RX0_IRQHandler(void);
void __attribute__ ((weak, alias ("default_handler"))) CAN1_RX1_IRQHandler(void);
void __attribute__ ((weak, alias ("default_handler"))) CAN1_SCE_IRQHandler(void);
void __attribute__ ((weak, alias ("default_handler"))) EXTI9_5_IRQHandler(void);
void __attribute__ ((weak, alias ("default_handler"))) TIM1_BRK_TIM9_IRQHandler(void);
void __attribute__ ((weak, alias ("default_handler"))) TIM1_UP_TIM10_IRQHandler(void);
void __attribute__ ((weak, alias ("default_handler"))) TIM1_TRG_COM_TIM11_IRQHandler(void);
void __attribute__ ((weak, alias ("default_handler"))) TIM1_CC_IRQHandler(void);
void __attribute__ ((weak, alias ("default_handler"))) TIM2_IRQHandler(void);
void __attribute__ ((weak, alias ("default_handler"))) TIM3_IRQHandler(void);
void __attribute__ ((weak, alias ("default_handler"))) TIM4_IRQHandler(void);
void __attribute__ ((weak, alias ("default_handler"))) I2C1_EV_IRQHandler(void);
void __attribute__ ((weak, alias ("default_handler"))) I2C1_ER_IRQHandler(void);
void __attribute__ ((weak, alias ("default_handler"))) I2C2_EV_IRQHandler(void);
void __attribute__ ((weak, alias ("default_handler"))) I2C2_ER_IRQHandler(void);
void __attribute__ ((weak, alias ("default_handler"))) SPI1_IRQHandler(void);
void __attribute__ ((weak, alias ("default_handler"))) SPI2_IRQHandler(void);
void __attribute__ ((weak, alias ("default_handler"))) USART1_IRQHandler(void);
void __attribute__ ((weak, alias ("default_handler"))) USART2_IRQHandler(void);
void __attribute__ ((weak, alias ("default_handler"))) USART3_IRQHandler(void);
void __attribute__ ((weak, alias ("default_handler"))) EXTI15_10_IRQHandler(void);
void __attribute__ ((weak, alias ("default_handler"))) RTC_Alarm_IRQHandler(void);
void __attribute__ ((weak, alias ("default_handler"))) OTG_FS_WKUP_IRQHandler(void);
void __attribute__ ((weak, alias ("default_handler"))) TIM8_BRK_TIM12_IRQHandler(void);
void __attribute__ ((weak, alias ("default_handler"))) TIM8_UP_TIM13_IRQHandler(void);
void __attribute__ ((weak, alias ("default_handler"))) TIM8_TRG_COM_TIM14_IRQHandler(void);
void __attribute__ ((weak, alias ("default_handler"))) TIM8_CC_IRQHandler(void);
void __attribute__ ((weak, alias ("default_handler"))) DMA1_Stream7_IRQHandler(void);
void __attribute__ ((weak, alias ("default_handler"))) FMC_IRQHandler(void);
void __attribute__ ((weak, alias ("default_handler"))) SDIO_IRQHandler(void);
void __attribute__ ((weak, alias ("default_handler"))) TIM5_IRQHandler(void);
void __attribute__ ((weak, alias ("default_handler"))) SPI3_IRQHandler(void);
void __attribute__ ((weak, alias ("default_handler"))) UART4_IRQHandler(void);
void __attribute__ ((weak, alias ("default_handler"))) UART5_IRQHandler(void);
void __attribute__ ((weak, alias ("default_handler"))) TIM6_DAC_IRQHandler(void);
void __attribute__ ((weak, alias ("default_handler"))) TIM7_IRQHandler(void);
void __attribute__ ((weak, alias ("default_handler"))) DMA2_Stream0_IRQHandler(void);
void __attribute__ ((weak, alias ("default_handler"))) DMA2_Stream1_IRQHandler(void);
void __attribute__ ((weak, alias ("default_handler"))) DMA2_Stream2_IRQHandler(void);
void __attribute__ ((weak, alias ("default_handler"))) DMA2_Stream3_IRQHandler(void);
void __attribute__ ((weak, alias ("default_handler"))) DMA2_Stream4_IRQHandler(void);
void __attribute__ ((weak, alias ("default_handler"))) CAN2_TX_IRQHandler(void);
void __attribute__ ((weak, alias ("default_handler"))) CAN2_RX0_IRQHandler(void);
void __attribute__ ((weak, alias ("default_handler"))) CAN2_RX1_IRQHandler(void);
void __attribute__ ((weak, alias ("default_handler"))) CAN2_SCE_IRQHandler(void);
void __attribute__ ((weak, alias ("default_handler"))) OTG_FS_IRQHandler(void);
void __attribute__ ((weak, alias ("default_handler"))) DMA2_Stream5_IRQHandler(void);
void __attribute__ ((weak, alias ("default_handler"))) DMA2_Stream6_IRQHandler(void);
void __attribute__ ((weak, alias ("default_handler"))) DMA2_Stream7_IRQHandler(void);
void __attribute__ ((weak, alias ("default_handler"))) USART6_IRQHandler(void);
void __attribute__ ((weak, alias ("default_handler"))) I2C3_EV_IRQHandler(void);
void __attribute__ ((weak, alias ("default_handler"))) I2C3_ER_IRQHandler(void);
void __attribute__ ((weak, alias ("default_handler"))) OTG_HS_EP1_OUT_IRQHandler(void);
void __attribute__ ((weak, alias ("default_handler"))) OTG_HS_EP1_IN_IRQHandler(void);
void __attribute__ ((weak, alias ("default_handler"))) OTG_HS_WKUP_IRQHandler(void);
void __attribute__ ((weak, alias ("default_handler"))) OTG_HS_IRQHandler(void);
void __attribute__ ((weak, alias ("default_handler"))) DCMI_IRQHandler(void);
void __attribute__ ((weak, alias ("default_handler"))) FPU_IRQHandler(void);
void __attribute__ ((weak, alias ("default_handler"))) SPI4_IRQHandler(void);
void __attribute__ ((weak, alias ("default_handler"))) SAI1_IRQHandler(void);
void __attribute__ ((weak, alias ("default_handler"))) SAI2_IRQHandler(void);
void __attribute__ ((weak, alias ("default_handler"))) QUADSPI_IRQHandler(void);
void __attribute__ ((weak, alias ("default_handler"))) CEC_IRQHandler(void);
void __attribute__ ((weak, alias ("default_handler"))) SPDIF_RX_IRQHandler(void);
void __attribute__ ((weak, alias ("default_handler"))) FMPI2C1_EV_IRQHandler(void);
void __attribute__ ((weak, alias ("default_handler"))) FMPI2C1_ER_IRQHandler(void);

__attribute__ ((section(".vectors"), used))
void (* const g_pfnVectors[])(void) = {
    (intfunc)((uint32_t)&_estack),
    reset_handler,
    NMI_Handler,
    HardFault_Handler,
    MemManage_Handler,
    BusFault_Handler,
    UsageFault_Handler,
    0,
    0,
    0,
    0,
    SVC_Handler,
    DebugMon_Handler,
    0,
    PendSV_Handler,
    SysTick_Handler,
    WWDG_IRQHandler,
    PVD_IRQHandler,
    TAMP_STAMP_IRQHandler,
    RTC_WKUP_IRQHandler,
    FLASH_IRQHandler,
    RCC_IRQHandler,
    EXTI0_IRQHandler,
    EXTI1_IRQHandler,
    EXTI2_IRQHandler,
    EXTI3_IRQHandler,
    EXTI4_IRQHandler,
    DMA1_Stream0_IRQHandler,
    DMA1_Stream1_IRQHandler,
    DMA1_Stream2_IRQHandler,
    DMA1_Stream3_IRQHandler,
    DMA1_Stream4_IRQHandler,
    DMA1_Stream5_IRQHandler,
    DMA1_Stream6_IRQHandler,
    ADC_IRQHandler,
    CAN1_TX_IRQHandler,
    CAN1_RX0_IRQHandler,
    CAN1_RX1_IRQHandler,
    CAN1_SCE_IRQHandler,
    EXTI9_5_IRQHandler,
    TIM1_BRK_TIM9_IRQHandler,
    TIM1_UP_TIM10_IRQHandler,
    TIM1_TRG_COM_TIM11_IRQHandler,
    TIM1_CC_IRQHandler,
    TIM2_IRQHandler,
    TIM3_IRQHandler,
    TIM4_IRQHandler,
    I2C1_EV_IRQHandler,
    I2C1_ER_IRQHandler,
    I2C2_EV_IRQHandler,
    I2C2_ER_IRQHandler,
    SPI1_IRQHandler,
    SPI2_IRQHandler,
    USART1_IRQHandler,
    USART2_IRQHandler,
    USART3_IRQHandler,
    EXTI15_10_IRQHandler,
    RTC_Alarm_IRQHandler,
    OTG_FS_WKUP_IRQHandler,
    TIM8_BRK_TIM12_IRQHandler,
    TIM8_UP_TIM13_IRQHandler,
    TIM8_TRG_COM_TIM14_IRQHandler,
    TIM8_CC_IRQHandler,
    DMA1_Stream7_IRQHandler,
    FMC_IRQHandler,
    SDIO_IRQHandler,
    TIM5_IRQHandler,
    SPI3_IRQHandler,
    UART4_IRQHandler,
    UART5_IRQHandler,
    TIM6_DAC_IRQHandler,
    TIM7_IRQHandler,
    DMA2_Stream0_IRQHandler,
    DMA2_Stream1_IRQHandler,
    DMA2_Stream2_IRQHandler,
    DMA2_Stream3_IRQHandler,
    DMA2_Stream4_IRQHandler,
    0,
    0,
    CAN2_TX_IRQHandler,
    CAN2_RX0_IRQHandler,
    CAN2_RX1_IRQHandler,
    CAN2_SCE_IRQHandler,
    OTG_FS_IRQHandler,
    DMA2_Stream5_IRQHandler,
    DMA2_Stream6_IRQHandler,
    DMA2_Stream7_IRQHandler,
    USART6_IRQHandler,
    I2C3_EV_IRQHandler,
    I2C3_ER_IRQHandler,
    OTG_HS_EP1_OUT_IRQHandler,
    OTG_HS_EP1_IN_IRQHandler,
    OTG_HS_WKUP_IRQHandler,
    OTG_HS_IRQHandler,
    DCMI_IRQHandler,
    0,
    0,
    FPU_IRQHandler,
    0,
    0,
    SPI4_IRQHandler,
    0,
    0,
    SAI1_IRQHandler,
    0,
    0,
    0,
    SAI2_IRQHandler,
    QUADSPI_IRQHandler,
    CEC_IRQHandler,
    SPDIF_RX_IRQHandler,
    FMPI2C1_EV_IRQHandler,
    FMPI2C1_ER_IRQHandler,
};

void crt0(void){
    uint32_t *src, *dst;

    src = &_textdata;
    dst = &_sdata;

    while(dst < &_edata)
        *(dst++) = *(src++);

    dst = &_bss_start;

    while(dst < &_bss_end)
        *(dst++) = 0;

    return;
}

void reset_handler(void){
    crt0();
    SystemInit();
    ClockInit();
    SystemCoreClockUpdate();
    main();
    while(1);
}

void default_handler(void){
    while(1);
}

void default_clock_init(void){
    return;
}

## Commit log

2023-03-11 Add schematic, documentation and STM32CubeMX configuration
    [low_level_io.kicad_sch, mcu.kicad_sch, memories.kicad_sch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]
2023-03-11 Replaced FTDI package with QFN one
    [stlinux.kicad_pcb, stlinux.kicad_sch, uart.kicad_sch]
2023-03-11 Added OSHW logo on the board
    [stlinux.kicad_pcb]
2023-03-11 Added more expansion capability.
    [low_level_io.kicad_sch, mcu.kicad_sch, memories.kicad_sch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]
2023-03-11 Add JLCPCB order ID placeholder under IC
    [stlinux.kicad_pcb]
2023-03-11 Add gerber from first prototypes
2023-05-06 Add board test code
2023-06-25 Gathered board files to one place
    [low_level_io.kicad_sch, mcu.kicad_sch, memories.kicad_sch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]
2024-08-10 Update board to revision 1.1
    HW bugs fixed:
    * SDIO bus missing pull-up resistors
    * USB bus to FTDI connected wrongly
    * Wrong package of QSPI Flash
    Additionally:
    * Updated version of CubeMX project
    * Updated version of KiCad project
    * Provided schematic in PDF format
    [low_level_io.kicad_sch, mcu.kicad_sch, memories.kicad_sch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]
